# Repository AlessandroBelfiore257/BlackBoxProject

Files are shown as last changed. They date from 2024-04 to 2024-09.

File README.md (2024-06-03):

# Black-box per flotte a noleggio: monitoraggio/tracking veicoli, segnalazione allarmi e profilazione guida

## Che cosa viene realizzato?
Progetto Open Source che prevede la realizzazione di una scatola nera collocabile all'interno di veicoli appartenenti ad una compagnia di autonoleggio; la black box è in grado di svolgere le seguenti funzionalità:
1. Monitoraggio dati e tracking del veicolo
2. Segnalazione di allarmi. Questi possono essere dovuti ad un rilevamento di una situazione di incidente, ad un malfunzionamento del veicolo o ad un comportamento non corretto da parte del guidatore
3. Profilazione guida: sulla base di alcuni parametri posso raggruppare i guidatori (i clienti dell'autonoleggio) in certi cluster e classificarli come prudenti o negligenti

## In che ambito utilizzarlo? 
La black box è un prodotto collocabile all'interno di qualsiasi tipo di veicolo appartenente ad una compagnia di autonoleggio. Nasce con l'obiettivo di agevolare e
migliorare il servizio offerto alla clientela della compagnia (soccorso in caso di incidente, carro attrezzi, rilevamento immediato di un malfunzionamento del veicolo...). Inoltre, grazie alle sue molteplici funzionalità, è possibile monitorare la guida di qualsiasi veicolo appartenente alla flotta.

## Perchè acquistare tale prodotto per la compagnia di autonoleggio?
- Monitoraggio dati veicolo
- Geolocalizzazione (utile anche in caso di furto oltre che per le emergenze)
- Emergenze (guasto, malessere, incidente)
- Rilevamento azioni non lecite eseguite sul veicolo noleggiato
- Profilazione del guidatore ("Pay-as-you-drive")
- Maggiori benefici per il cliente: assistenza immediata per qualsiasi situazione "scomoda"

## Risorse utilizzate 
- OBD elm 327 bluetooth
- ESP32
- GPS GY-NEO 6M
- Accelerometro GY-521
- RTC DS3231 I2C
- Display LCD
- Sensore di Gas, Fumo e Qualità dell'Aria MQ-2
- Sensore di alcool MQ-3
- 3 Led
- 3 Resistori
- 1 Bottone
- 2 Breadboard da 830 pin
- Diversi jumper di lunghezza variabile
- Power bank

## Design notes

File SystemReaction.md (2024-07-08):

_A seguito di una particolare situazione riconosciuta dai sensori viene descritto il funzionamento/comportamento atteso della black box_

## Azione-reazione
### Le funzionalità sono 3:
#### Tracking:
Invio coordinate GPS (latitudine e longitudine e direzione) ad un server remoto, immagazzino i dati e dopo averne raccolti abbastanza provare a ricostruire il tragitto percorso.
#### Seganalazione allarmi:
- Assistenza incidente:
Simulare una dinamica di incidente e verificare che venga notificata la centrale operativa con tutte le informazioni utili (G-force, velocità, latitudine, longitudine e momento dell'impatto).
- Assistenza cliente:
Simulare entrambe le features (Invio notifica a server remoto per qualsiasi bisogno e invio notifica a server remoto per necessità di carroattrezzi), con "invio notifica" si intende che il server remoto riceva una notifica da un qualunque veicolo dell'autonoleggio con un opportuno messaggio che ne indica la descrizione del problema e con le informazioni utili ad esempio coordinate gps in caso di notifica per carroattrezzi.
- Avvertimento di alcuni sistemi non funzionanti / segnalazione di alcune situazioni anomalie: 

_*LED GIALLO:*_

1) Simulare la presenza di fumo nell'abitacolo, verificare l'accensione del led giallo e la notifica al conducente, se ne viene rilevata la presenza per un periodo prolungato e continuo (2/3 giorni) avvisare la centrale del comportamento scorretto del cliente.

2) Rilevamento guida su terreni non asfaltati con la modifica di alcuni dati ottenuti dall'accelerometro, verificare l'accensione del led giallo e la notifica al conducente, se viene rilevata un'attività frequente in fuori strada viene contattata la centrale.

3) Rilevamento guida in zona non autorizzata grazie alle coordinate GPS, verificare l'accensione del led giallo e la relativa notifica al conducente. Se la posizione del veicolo continua ad essere al di fuori del range voluto, viene inviata una notifica alla centrale operativa.

4) Rilevamento attività di rimorchio, se viene rilevata un'attività di trasporto viene azionato il led giallo e mandata una notifica al conducente, dopo un periodo prestabilito viene avvisata la centrale dell'attività non lecita.

_*LED ROSSO:*_  

1) A seguito di più rilevamenti di una frenata anomala, viene immediatamente segnalato alla centrale il guasto, inoltre il led rosso viene acceso. 

2) Il consumo anomalo di carburante viene rilevato a seguito del trasferimento dei dati ad un server remoto e a seguito di un'accurata analisi di essi, lo stato del led risulta essere rosso.

3) La qualità dell'aria e l'alcool possono essere simulate con la relativa presenza di scarsa Co2 o presenza di alcool, per verificarne il corretto funzionamento è necessario che il led assuma lo stato rosso e che venga segnalata la situazione con un opportuno messaggio al cliente e alla centrale.

4) Modificando i dati della rete can bus: temperatura del liquido di raffreddamento, temperatura dell'olio motore e la coppia del motore con opportuni valori critici, il sistema deve reagire inviando un opportuno segnale al conducente e alla centrale operativa e con l'azionamento del led rosso.

#### Profilazione guida
Si propone di eseguire ripetutamente lo stesso percorso in automobile, affrontandolo con tre distinti stili di guida: tranquillo, moderato e brusco, al fine di valutare e confrontare gli effetti di tali stili sulla dinamica di guida. Si osserverà un diverso score ottenuto dalla board nei tre casi distinti.

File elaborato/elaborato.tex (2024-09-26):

%%%%%%%%%%%%%%%%%%%%%%%%%%%%%%%%%%%%%%%%%%%%%%%%%%%%%%
\documentclass[12pt, a4paper, italian]{report}
\usepackage{template}  % Assicurati che questo pacchetto esista e non crei conflitti

\usepackage[colorinlistoftodos]{todonotes}
\usepackage{tikz}
\usepackage{tocloft}
\usepackage{adjustbox}
\usepackage{amsmath}
\usepackage[utf8]{inputenc}
\usepackage{listings}
\usepackage{xcolor}

\numberwithin{figure}{chapter}
\numberwithin{table}{chapter}

\usetikzlibrary{shapes.geometric, arrows, positioning, calc}

\lstset{
  language=C++,
  basicstyle=\ttfamily\small\color{black}, % Codice in nero
  keywordstyle=\bfseries,
  commentstyle=\itshape,
  stringstyle=\color{red},
  numberstyle=\tiny\color{gray},
  numbersep=5pt,
  frame=single, % Bordo attorno al codice
  rulecolor=\color{black}, % Colore del bordo
  backgroundcolor=\color{white}, % Sfondo bianco
  tabsize=2,
  breaklines=true,
  breakatwhitespace=false,
  showspaces=false,
  showtabs=false,
  numbers=left,
  showstringspaces=false
}

\tikzstyle{startstop} = [rectangle, rounded corners, minimum width=3cm, minimum height=1cm, text centered, draw=black, fill=red!30]
\tikzstyle{process} = [rectangle, minimum width=3cm, minimum height=1cm, text centered, draw=black, fill=orange!30]
\tikzstyle{decision} = [diamond, aspect=2, minimum width=3cm, minimum height=1cm, text centered, draw=black, fill=green!30]
\tikzstyle{arrow} = [thick,->,>=stealth]

%%%%%%%%%%%%%%%%%%%%%%%%%%%%%%%%%%%%%%%%%%%%%%%%%%%%%%
% packages...
% Package di formato
\usepackage[a4paper]{geometry}		% Formato del foglio
\usepackage[italian]{babel}			% Supporto per l'italiano
\usepackage{lscape}
%\usepackage[a-1b]{pdfx}			% File conforme allo standard PDF-A (obbligatorio per la consegna)

% Package per la grafica
\usepackage{graphicx}				% Funzioni avanzate per le immagini
\usepackage{hologo}					% Bibtex logo with \hologo{BibTeX}
\usepackage{enumitem}

% Citazioni e bibliografia
\usepackage[style=italian]{csquotes}
\usepackage[backend=biber,style=numeric,sorting=none]{biblatex}
\addbibresource{bibliografia.bib}
\usepackage[toc]{appendix}
\usepackage{epigraph}

% Package tipografici
\usepackage{lmodern,textcomp}		% Latin Modern font
\usepackage{amssymb,amsmath,amsthm} % Simboli matematici

% Sistema note a pié di pagina nelle tabelle e nelle figure
\usepackage{footnote}
\makesavenoteenv{tabular}
\makesavenoteenv{table}
\makesavenoteenv{figure}

% Package ipertesto
\usepackage{url}					% Visualizza e rende interattivi gli URL
\usepackage{hyperref}				% Rende interattivi i collegamenti interni

% Path immagini
\graphicspath{ {./images/} }

% Configurazione dei piè di pagina
\usepackage{fancyhdr}  % Per configurare intestazioni e piè di pagina
\pagestyle{fancy}
\fancyhf{}
\fancyfoot[C]{\thepage}  % Piè di pagina centrato con numero di pagina
%%%%%%%%%%%%%%%%%%%%%%%%%%%%%%%%%%%%%%%%%%%%%%%%%%%%%
\setlength {\marginparwidth }{2cm}
\begin{document}

% Frontespizio
\begin{titlepage}
\begin{center}
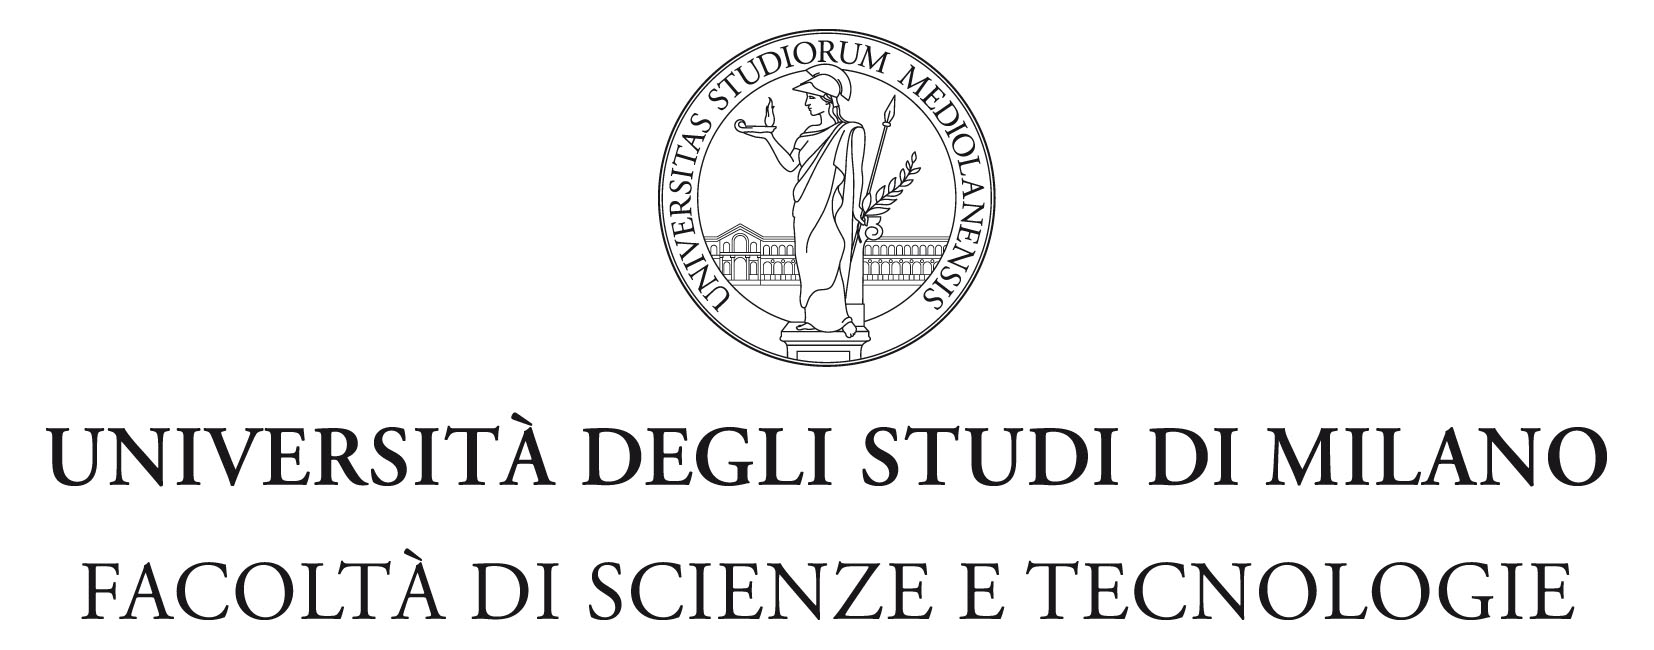
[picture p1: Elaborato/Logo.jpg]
\\
{\large{\bf Corso di Laurea in Informatica}}
\end{center}
\vspace{12mm}
\begin{center}
{\huge{\bf Black-box per flotte a noleggio: monitoraggio/tracking veicoli, segnalazione allarmi e profilazione guida}}\\
\end{center}
\vspace{12mm}
\begin{flushleft}
{\large{\bf Relatore: Prof. Andrea Trentini}}
{\large{}}\\
\vspace{4mm}
{\large{\bf Correlatore: Dott. Alexjan Carraturo}}
{\large{}}\\
\end{flushleft}
\vspace{12mm}
\begin{flushright}
{\large{\bf Tesi di Laurea di:}}
{\large{Alessandro Belfiore}}\\
{\large{\bf Matr. 975826}}\\
\end{flushright}
\vspace{4mm}
\begin{center}
{\large{\bf Anno Accademico 2023/2024}}
\end{center}
\end{titlepage}

\newpage
\thispagestyle{empty}
\null
\newpage

\tableofcontents

% o sections (dipende dal documentclass)
\chapter{Introduzione}
Il settore assicurativo è stato tra i primi ad intuire le potenzialità del tracciamento GPS per monitorare gli spostamenti di un automobilista ed assisterlo in caso di emergenza. Ad esempio, in caso di incidente, il GPS può segnalare la posizione esatta ai soccorsi o, in caso di furto, informare le forze dell'ordine in tempo reale. Queste funzionalità sono rese possibili dall'introduzione della cosiddetta “scatola nera” o black-box: un piccolo dispositivo installato sull'auto dell'assicurato, capace di registrare non solo tutti gli spostamenti dell'auto, ma anche il comportamento di guida del conducente. La black-box può essere utilizzata dalle compagnie assicurative per profilare i clienti, offrendo polizze personalizzate e adattate al tipo di utilizzo del veicolo.\cite{fracassi2012} % \todo{AT: fai uno spellcheck, accenti sbagliati}
%\todo{AT: accennare già al fatto della profilazione?}
\section{Cos'è una scatola nera?}
La black-box è un dispositivo elettronico utilizzato principalmente per monitorare e registrare vari parametri di funzionamento del veicolo e il comportamento del conducente. Nonostante il termine sia spesso associato alle registrazioni di volo degli aerei, nel contesto automobilistico e assicurativo, la scatola nera ha una funzione leggermente diversa ma altrettanto cruciale. Si presenta una descrizione dettagliata nei due paragrafi seguenti:

\begin{figure}[h] \centering
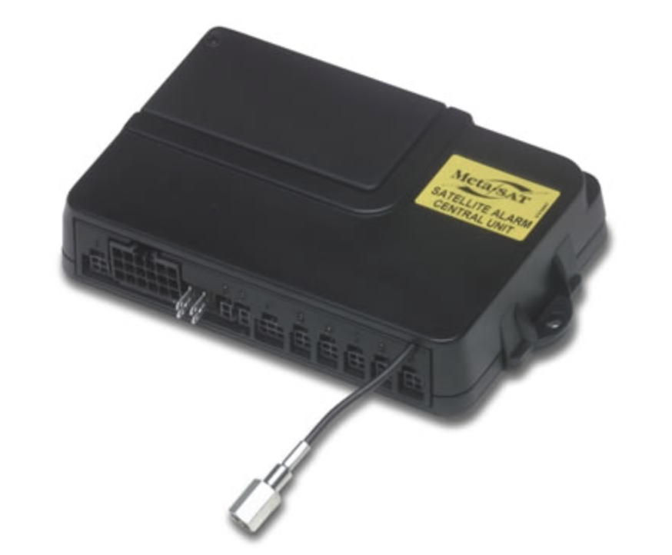
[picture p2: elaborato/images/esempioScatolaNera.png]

\caption{Esempio di scatola nera\protect\footnotemark (fonte: driving test tips)}
\label{fig:scatolaNera}
\end{figure}
\footnotetext{Presa da: \url{https://www.drivingtesttips.biz/wp-content/uploads/2016/01/car-insurance-black-box.jpg}}

\subsection{Utilità}
\begin{itemize}
    \item \textbf{Tracciamento GPS}: registra i movimenti del veicolo, inclusi i percorsi effettuati, le velocità raggiunte e le soste. Questo permette di localizzare il veicolo in caso di furto e di fornire assistenza immediata in caso di emergenza.\cite{khin2018real}
    \item \textbf{Monitoraggio del comportamento di guida}: registra il comportamento del conducente, come accelerazioni brusche, frenate improvvise, velocità eccessive e svolte pericolose. Questi dati permettono di valutare lo stile di guida e possono essere utilizzati per migliorare la sicurezza stradale.\cite{hermawan2020acquisition}
    \item \textbf{Supporto in caso di incidenti}: fornisce dati cruciali sugli incidenti, come la velocità al momento dell'impatto e la posizione esatta dell'incidente. Queste informazioni possono essere molto importanti per le indagini post-incidente e per la richiesta di soccorsi. \cite{thompson2010using}
\end{itemize}
\subsection{Importanza}
L'importanza di una black-box è data dai benefici che si possono trarre da essa: 
\begin{itemize}
    \item \textbf{Assistenza rapida}: in caso di incidente, la scatola nera può inviare automaticamente la posizione ai servizi di emergenza, riducendo i tempi di risposta.
    \item \textbf{Recupero dei veicoli rubati}: la localizzazione GPS permette di tracciare e recuperare rapidamente veicoli rubati, a meno che il dispositivo non venga rimosso o disattivato. % \todo{AT: se non lo rimuovono/staccano}
    \item \textbf{Polizze assicurative personalizzate}: le compagnie assicurative possono utilizzare i dati registrati per profilare i clienti e offrire polizze personalizzate basate sul comportamento alla guida e sull'uso del veicolo, incentivando una guida più responsabile attraverso sconti per chi mantiene uno stile di guida prudente.
    \item \textbf{Miglioramento della sicurezza}: i dati raccolti possono essere utilizzati per educare i conducenti a comportamenti di guida sicuri, contribuendo a ridurre il rischio di incidenti. Un'indagine dell'ANIA (Associazione Nazionale delle Imprese Assicurative) ha stabilito che chi installa una black-box ha una condotta di guida più responsabile \cite{diminuzioneIncidenti}, diminuendo quindi la probabilità di provocare sinistri. Lo studio, precedentemente citato, ha rilevato una riduzione della sinistrosità per i veicoli controllati dal congegno quasi doppia rispetto a quella delle auto che non montano il sistema di sorveglianza. % \todo{AT: prima o poi mi aspetto considerazioni sull'aspetto privacy} -> Aggiunte al capitolo 2.4
\end{itemize}
\section{Obiettivi del progetto}
Il principale obiettivo di questo progetto è quello di sviluppare una black-box avanzata per veicoli appartenenti ad una flotta di autonoleggio a lungo termine, che si distingua dalle soluzioni tradizionali per la sua capacità di diagnosticare sia il veicolo che il comportamento del conducente. Le tradizionali black-box non solo registrano i dati di viaggio, ma svolgono anche funzioni fondamentali come il monitoraggio costante del veicolo, il tracciamento degli incidenti e la richiesta automatica di assistenza in caso di emergenza. La black-box di cui tratta questo elaborato, oltre a queste funzionalità di base, introduce due caratteristiche innovative che ne ampliano ulteriormente le potenzialità.

\vspace{1cm}

La \textbf{prima caratteristica distintiva} è la capacità di rilevare e segnalare tempestivamente sia allarmi critici che di minore gravità, relativi a problemi meccanici del veicolo e comportamenti inappropriati del conducente. Questo sistema avanzato di diagnostica è in grado di identificare malfunzionamenti interni dell'autovettura, come anomalie nel motore, nonché situazioni di pericolo come la presenza di gas nell'abitacolo. Inoltre, è capace di monitorare e segnalare comportamenti non leciti del conducente: la presenza di fumo nell'abitacolo (che potrebbe essere un vincolo da rispettare imposto dalla compagnia), la guida sotto l'effetto di alcolici, l'utilizzo del veicolo su strade non asfaltate, la guida fuori dal territorio nazionale o il trasporto di un rimorchio senza autorizzazione.

\vspace{1cm}

La \textbf{seconda caratteristica innovativa} è la generazione automatica di un punteggio di guida per il conducente. Tale punteggio viene calcolato sulla base dei dati raccolti durante la guida, valutando il comportamento al volante del conducente. Il punteggio serve non solo come feedback per il conducente, aiutandolo a migliorare le proprie abitudini di guida, ma potrebbe essere anche utilizzato dalle compagnie assicurative per offrire polizze personalizzate e vantaggiose, stimolando il conducente a mantenere uno stile di guida più prudente. È importante sottolineare che questa profilazione del conducente non richiede l'intervento di un esperto lato server remoto, poiché è la stessa black-box ad elaborare e generare automaticamente il punteggio di guida.

\vspace{1cm}

Il progetto mira a creare una black-box che non solo registra e monitora i dati di viaggio e le condizioni del veicolo, ma offre anche un sistema di diagnostica integrato in grado di riconoscere malfunzionamenti interni del veicolo, comportamenti inappropriati del conducente e la capacità di valutare quest'ultimo sulla base del suo stile di guida; migliorando sicurezza ed efficienza del veicolo e contribuendo ad una guida più responsabile e consapevole.

\chapter{Stato dell'arte}
La \textbf{scatola nera}, chiamata anche black-box o EDR (Event Data Recorder, ovvero registratore di dati di evento), è un dispositivo che registra dati come la posizione (determinata tramite GPS), la velocità, le accelerazioni, le decelerazioni, le frenate e la frequenza di attivazione dei sistemi di sicurezza, trasmettendoli poi a una centrale operativa.
Quelle che sono comunemente indicate come ``scatole nere" sono localizzatori satellitari GPS installati a bordo dell'auto, ideate dalle assicurazioni come strumento con lo scopo di ridurre le \textbf{frodi assicurative}.
\section{Gestioni attuali di tracking per veicoli}
Il principale vantaggio del tracking dei veicoli è quello di facilitare il rintracciamento del veicolo in caso di furto, grazie al localizzatore GPS. Naturalmente, il localizzatore ha un ruolo rilevante anche nella gestione degli incidenti, come verrà discusso nel prossimo paragrafo.
% \todo{AT: italiano da rivedere!}
\section{Gestioni attuali delle emergenze e dei sistemi di allarmi in uso}
\subsection{Vantaggi e Svantaggi nella gestione delle emergenze}
\subsubsection{Vantaggi}
Grazie all'installazione di una black-box sul proprio veicolo, al monitoraggio continuo e al tracking di esso, è possibile, in caso di incidente, visualizzare il luogo dell'accaduto immediatamente e ricostruire con precisione la dinamica degli incidenti stradali. Tramite questo strumento le compagnie assicurative sono in grado di ricostruire più facilmente la dinamica di un sinistro stradale. Questo non solo avvantaggia la compagnia, ma anche il guidatore, che vedrà diminuire il tempo
%\todo{AT: o anche però non vedersi rimborsare perché gli affibbiano la colpa, senza possibilità di contestazione} -> inserita questa considerazione nella sezione svantaggi
per ottenere il risarcimento del danno, dato che grazie alla black-box è possibile evitare le lunghe procedure per l'accertamento delle responsabilità in un incidente.
\subsubsection{Svantaggi}
Le black-box attuali sono in grado di registrare la velocità del veicolo e questo fa si che in un ipotetico incidente senza alcun tipo di colpa, se fosse stata registrata una velocità anche poco sopra al limite, si potrebbe riconoscere al guidatore una piccola parte di responsabilità nel sinistro. Questo aspetto sottolinea un potenziale rischio per il guidatore: \textbf{sebbene la black-box possa accelerare il processo di risarcimento, potrebbe anche attribuire la colpa o una responsabilità parziale in modo inequivocabile, rendendo difficile contestare tale decisione}. Questo non solo potrebbe portare ad una riduzione del risarcimento, ma anche causare conseguenze legali o assicurative impreviste per il guidatore.

\vspace{1cm}

Nei vari contratti di noleggio \cite{hertz_pdf} vengono proposti dei termini e delle condizioni sull'utilizzo dell'autovettura, quali ad esempio non utilizzare il veicolo nelle seguenti condizioni: 
\begin{itemize}
    \item  sotto l'effetto di alcool.
    \item da persone sprovviste di patente o con validità scaduta.
    \item fuori strada o su strade inadatte.
    \item per recarsi all'estero salva preventiva autorizzazione concessa dal noleggiante.
    \item per trainare o spingere qualsiasi altro veicolo, rimorchio o oggetto senza consenso del noleggiatore.
\end{itemize}
Tutti questi divieti vengono citati all'interno del contratto assicurativo, non è possibile però stabilire se uno tra questi non dovesse essere rispettato.

\section{Soluzioni esistenti per la profilazione guidatori}
Alcune grandi compagnie di assicurazioni, quali ad esempio \textbf{Generali}, propongono il servizio \textbf{stile di guida} che permette di ottenere ulteriori sconti sulla polizza negli anni a seguire \cite{Generali}. Si tiene a precisare la parola ``ulteriori" dato che già l'installazione di una black-box prevede uno sconto compreso tra il 15/20\%, sul totale dell'assicurazione.% \todo{AT: il costo effettivo è in realtà nascosto, perché l'assicurazione ha più leva per non pagarti, inoltre paghi con la rinuncia alla tua privacy}

\section{Privacy e tutela dei dati}
Il Regolamento europeo vieta espressamente che la scatola nera registri conversazioni o usi i dati sensibili del guidatore, consentendo così l'anonimato del conducente e l'accesso ai dati solo in caso di collisione \cite{RegolamentoEU}.
La scatola nera ha sollevato molti \textbf{dubbi sulla questione privacy} dei clienti. Infatti, i dati vengono raccolti in un database e possono essere elaborati e analizzati soltanto dagli addetti ai lavori. Questa procedura insospettisce i clienti sul possibile \textbf{uso improprio} dei dati che, per esempio, potrebbero essere utilizzati a fini commerciali dalle compagnie assicurative per proporre prodotti ad hoc a prezzi non troppo vantaggiosi. Tuttavia, l’\textbf{ANIA} (Associazione Nazionale fra le Imprese Assicuratrici) assicura che \textbf{le compagnie sono a conoscenza soltanto dei dati che il cliente autorizza a far conoscere} firmando il modulo per la tutela approvato dal GDPR \cite{Generali}.

\section{Quanto è comune la scatola nera in Italia?}
L'uso della scatola nera in Italia inizia ad essere rilevante. Il trend di crescita non si è mai interrotto negli ultimi 10 anni e la percentuale di auto dotate di black-box è passata dal 6\% del 2013 al 23,2\% del 2020 (primo semestre)  \cite{Telepass}. I dati del 2021 del report IVASS confermano una diffusione più alta nei centri urbani del Sud Italia, come Caserta (65,5\%), Napoli (52,5\%) e Reggio Calabria (38,6\%). Le percentuali calano sotto il 10\% nelle città e nelle province del Nord come Udine (9\%), Trento (8\%), Belluno (7,3\%) e Bolzano (4,4\%). Tuttavia, è importante non considerare tali dati come indicatori della prudenza degli automobilisti nelle aree citate, in quanto, la maggior diffusione della black-box nelle regioni del sud Italia, dove i premi assicurativi sono più elevati e in alcune regioni possono arrivare a diverse migliaia di euro all'anno, è principalmente correlata alla possibilità di ottenere sconti significativi sulla polizza, compensando così tali costi elevati.

\chapter{Funzionalità del sistema}
\section{Monitoraggio}
Il monitoraggio consiste nella raccolta dati di alcuni parametri provenienti dal lettore OBD \ref{sec:capitolo432} % \todo{AT: la prima volta che usi un termine non di uso comune devi spiegarlo o mettere un rimando (anche in avanti) alla spiegazione} 
e da alcuni sensori installati sulla black-box. 
Il motivo per cui si è scelto di monitorare lo stato del veicolo è quello di ottenere una visione completa della sua salute. In particolare, i dati che vengono registrati sono: l'\textbf{accelerazione}, misurata grazie ad un accelerometro, utile per analizzare il comportamento dinamico del veicolo; la \textbf{presenza di vapori alcolici} nell'abitacolo, rilevata da un sensore per garantire la sicurezza del conducente e dei passeggeri; per assicurare una \textbf{qualità dell'aria} adeguata all'interno del veicolo, viene utilizzato un sensore specifico che rileva vari inquinanti. Il modulo GPS fornisce \textbf{coordinate} precise, fondamentali sia per la tracciabilità del veicolo in caso di furto sia per analizzare i percorsi abituali. Attraverso un lettore OBD, inoltre, viene monitorata  costantemente la \textbf{temperatura del liquido di raffreddamento} e dell'\textbf{olio motore}. Vengono poi registrati la \textbf{coppia del motore} per valutare le sue prestazioni e il \textbf{voltaggio della batteria} per prevenire problemi elettrici.
Infine, il dato relativo al \textbf{livello del carburante} permette di tenere traccia dell'autonomia del veicolo. 
\section{Tracking}
Questa funzionalità del sistema viene adoperata per localizzare i veicoli della flotta \cite{al2012hybrid}. Il sistema di tracking è in grado di generare la posizione esatta del veicolo usando due parametri: la latitudine e la longitudine. I dati di geolocalizzazione, per ogni slot temporale di 2 minuti, vengono trasferiti al server remoto della centrale operativa dell'autonoleggio. A posteriori potrebbero essere utilizzati per visualizzare i percorsi abituali del cliente o il percorso effettuato un preciso giorno. Il sistema di tracking è utile soprattutto in caso di furto del veicolo.
Infatti, il ricevitore GPS riceve informazioni dal satellite nel formato NMEA (National Marine Electronics Association), quest'ultime vengono processate dall'esp32 e trasmesse al server remoto via GSM. Il server, una volta ricevuto i dati, li memorizza in locale per analisi future. 

\begin{figure}[h] \centering
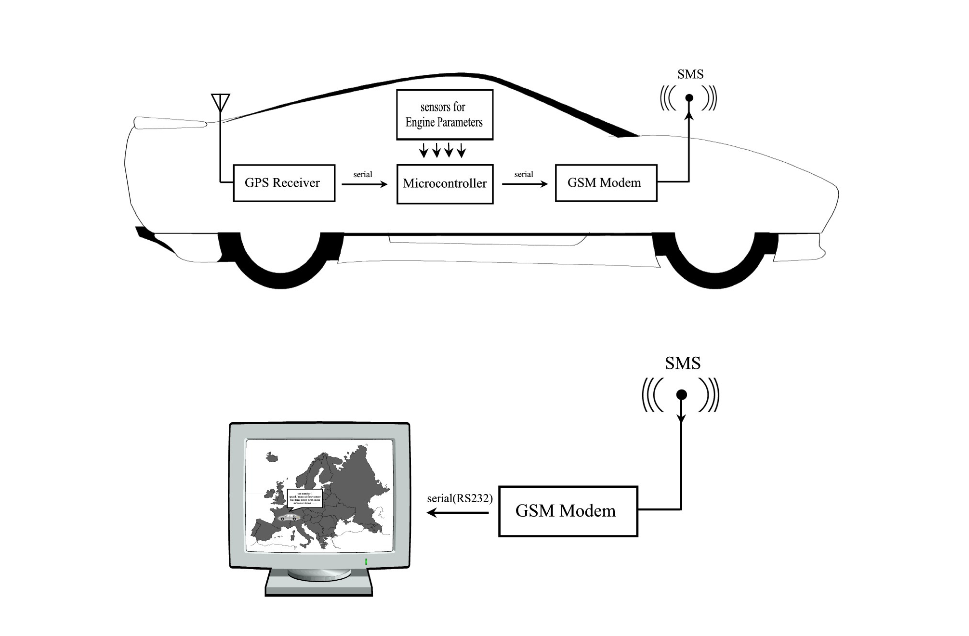
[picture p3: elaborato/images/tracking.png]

\caption{L'architettura del sistema: localizzazione GPS e modulo GSM\protect\footnotemark (fonte: ResearchGate)}
\label{fig:trackingGPS}
\end{figure}
\footnotetext{Presa da: \url{https://www.researchgate.net/profile/Mohammad-Alkhedher/publication/51989090/figure/fig5/AS:668830275760151@1536472972974/The-system-architecture-GPS-tracking-and-GS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}}

In molti casi il GPS potrebbe fornire una risposta errata o non sufficientemente precisa, dovuta a molti fattori esterni quali: condizioni del tempo atmosferico e/o dell'ambiente che circonda il veicolo.

\section{Segnalazione di allarmi}
Il meccanismo di segnalazione allarmi prevede 3 diversi tipi di dinamiche che verranno presentate in dettaglio nei seguenti paragrafi. 
\subsection{Incidente}
L'assistenza incidente tratta la dinamica relativa ad un incidente stradale, inviando le coordinate GPS ed un insieme di informazioni utili ad una stazione remota dell'autonoleggio. Sarà compito della stazione avvisare i soccorsi che si recheranno nel preciso punto di impatto. 
\begin{figure}[h] \centering
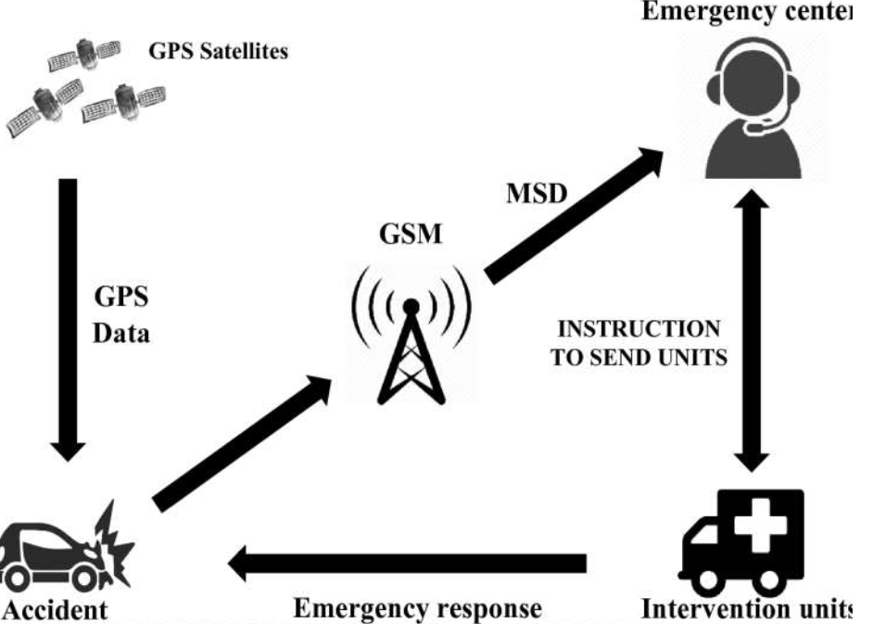
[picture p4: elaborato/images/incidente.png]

\caption{Situazione di emergenza dovuta ad un incidente\protect\footnotemark (fonte: ResearchGate)}
\label{fig:emergenzaIncidente}
\end{figure}
\footnotetext{Presa da: \url{https://www.researchgate.net/publication/51989090_Hybrid_GPS-GSM_localization_of_automobile_tracking_system}}

Sostanzialmente, il meccanismo si divide in due fasi: \textbf{rilevamento} e \textbf{notifica}, vedi figura \ref{fig:rilevamentoInvioIncidente}.
% \todo{AT: i diarammi di flusso sanno di ``antico'', li ridurrei in dimensione o eliminerei} -> ne ho ridotto le dimensioni 
\begin{figure}[h]
    \centering
    \resizebox{0.5\textwidth}{!}{
        \begin{tikzpicture}[node distance=2cm]

        % Nodi del diagramma
        \node (start) [startstop] {Start};
        \node (readsensor) [process, below of=start] {Read the status of sensor};
        \node (readgps) [process, below of=readsensor] {Read the data from GPS};
        \node (decision) [decision, below of=readgps, yshift=-1cm] {Sensor is triggered?};
        \node (sendSMS) [process, right of=decision, xshift=4cm] {Send SMS using GSM};
        \node (end) [startstop, below of=sendSMS] {End};

        % Frecce del diagramma
        \draw [arrow] (start) -- (readsensor);
        \draw [arrow] (readsensor) -- (readgps);
        \draw [arrow] (readgps) -- (decision);

        % Etichette ``Yes" e ``No"
        \node at ($(decision.west)!-0.2!(readsensor.east)$) [yshift=3cm] {No};
        \node at ($(decision.east)!0.5!(sendSMS.west)$) [yshift=0.3cm] {Yes};

        \draw [arrow] (decision) -| ++(-3,0) |- (readsensor);
        \draw [arrow] (decision) -- (sendSMS);
        \draw [arrow] (sendSMS) -- (end);

        \end{tikzpicture}
    }
    \caption{Diagramma di flusso per il monitoraggio dell'accelerometro ed eventuale invio SMS}
    \label{fig:rilevamentoInvioIncidente}
\end{figure}

I sensori maggiormente coinvolti sono l'accelerometro, il GPS e il dato relativo alla velocità del veicolo, proveniente dalla rete can bus. Nella fase di campionamento, l'accelerometro continua ad estrarre informazioni relative alla forza G sperimentata dagli occupanti. Il GPS, nella fase di notifica, è utile per inviare le coordinate alla stazione remota. Infine, la velocità del veicolo, coinvolta sempre in fase di notifica, viene mandata alla stazione remota e può essere utilizzata per future ricostruzioni/analisi dell'incidente. \cite{shubham2021survey}

Per il rilevamento di una situazione di incidente, si può utilizzare un accelerometro. In un evento di questo tipo la black-box subirà la stessa accelerazione degli occupanti del veicolo. La forza G che si ricava dall'accelerazione deve essere ragionevolmente alta per un incidente, per questo non vengono considerati incidenti se tutte le accelerazioni sono inferiori a 4G \cite{thompson2010using}. A tale proposito, sulle auto gli airbag non vengono altro che azionati dal superamento di una certa soglia di accelerazione. Come secondo filtro, viene utilizzato un sistema di conferma per evitare i falsi positivi: all'utente vengono concessi 30 secondi per annullare il rilevamento della situazione di incidente, terminato questo breve periodo, il messaggio verrà trasmesso al server remoto in automatico, in caso di annullamento si ritornerà ad una situazione di partenza, vedi figura \ref{fig:diagramma-flusso-incidenti}.

\begin{figure}[h]
    \centering
    \resizebox{0.5\textwidth}{!}{
    \begin{tikzpicture}[node distance=2cm, every node/.style={font=\small}]

    % Nodi del diagramma
    \node (start) [startstop] {Start};
    \node (readdata) [process, below of=start] {Read data};
    \node (gforcetriggered) [decision, below of=readdata] {G force triggered?};
    \node (incidentdetection) [process, below of=gforcetriggered, yshift=-0.5cm] {Rilevamento incidente};
    \node (userabort) [decision, below of=incidentdetection, yshift=-0.5cm] {User abort?};
    \node (sendSMS) [process, right of=userabort, xshift=3cm] {Send accident SMS};
    \node (end) [startstop, below of=sendSMS] {End};

    % Etichette ``Yes" e ``No"
    \node at ($(gforcetriggered.east)!0.5!(readdata.east)$) [xshift=1.3cm] {No};
    \node at ($(gforcetriggered.south)!0.5!(incidentdetection.north)$) [xshift=0.5cm] {Yes};
    \node at ($(userabort.east)!0.5!(sendSMS.west)$) [yshift=0.3cm] {No};
    \node at ($(readdata.south)!0.5!(userabort.north)$) [xshift=-3.2cm] {Yes};

    % Frecce del diagramma
    \draw [arrow] (start) -- (readdata);
    \draw [arrow] (readdata) -- (gforcetriggered);
    \draw [arrow] (gforcetriggered) -- (incidentdetection);
    \draw [arrow] (incidentdetection) -- (userabort);
    \draw [arrow] (userabort.west) -| ++(-1,0) |- (readdata.west);
    \draw [arrow] (gforcetriggered.east) -| ++(0.5,0) |- (readdata.east);
    \draw [arrow] (userabort) -- (sendSMS);
    \draw [arrow] (sendSMS) -- (end);

    \end{tikzpicture}
    }
    \caption{Diagramma di flusso per il rilevamento di incidenti e invio SMS}
    \label{fig:diagramma-flusso-incidenti}
\end{figure}

\begin{flushleft}
    \begin{minipage}[t]{0.3\textwidth}
        \scriptsize
        \begin{align*}
            \text{Incidente} &= I \\
            \text{Accident\_threshold} &= 1 \\
        \end{align*}
    \end{minipage}
    \vspace{0.5cm} % Aggiunge uno spazio verticale tra la legenda e la formula
    \begin{minipage}[t]{0.7\textwidth}
        \begin{align*}
            I &= 
            \begin{cases}
                1 & \text{se } \left( \frac{\text{Accelerazione}}{4G} \right) \geq \text{Accident\_threshold} \text{ \&\& } \neg\text{userAbort} \\
                0 & \text{altrimenti}
            \end{cases}
        \end{align*}
    \end{minipage}
\end{flushleft}

A seguito dell'incidente, le informazioni che possono essere trasmesse sono: la \textbf{forza G}, per capire quanto effettivamente è stato forte l'impatto, la \textbf{velocità del veicolo}, per capire a quanto quest'ultimo stava andando, le \textbf{coordinate GPS}, per individuare il luogo in cui è avvenuto l'incidente e in che \textbf{momento} questo è avvenuto.

\subsection{Assistenza}
Il sistema include un pulsante che permette al conducente di comunicare direttamente con il server remoto (la centrale dell'autonoleggio), inviando un messaggio tramite GSM in caso di necessità.
\subsection{Rilevamento allarmi}
Il rilevamento di allarmi consiste nell'avvertire il conducente e la centrale dell'autonoleggio di alcuni sistemi del veicolo non funzionanti e/o di alcuni comportamenti non corretti da parte del conducente. Per gestire tale situazione, la black-box viene dotata di 3 led per indicare diversi tipi di situazioni e per suggerire al cliente il corretto comportamento da intraprendere nel caso dell'accensione di una spia (led) indicante una situazione di avvertimento o pericolo. 
\begin{itemize}
    \item Il led \textbf{verde} indica che il veicolo \textbf{funziona correttamente} e il \textbf{comportamento} del conducente è \textbf{corretto}.
    \item Il led \textbf{giallo} indica un \textbf{avvertimento}. Se vengono rilevati problemi di poca rilevanza o eseguite azioni non lecite, viene azionato il led. Dopo aver superato una certa soglia di tolleranza, indicante il numero di volte in cui è stato rilevato il problema o eseguita l'azione non lecita, viene avvertita la centrale operativa. Il motto di questa spia è: se un problema di poca rilevanza o un'azione non lecita persistono, avverto la centrale.
    \item Il led \textbf{rosso} indica una situazione di \textbf{pericolo}. In questo caso la centrale operativa viene avvertita immediatamente.
\end{itemize}

Di seguito verranno proposte le dinamiche delle situazioni per le quali viene attivata una spia gialla piuttosto che una rossa.

\subsubsection{Non critici (led giallo)}

\begin{itemize}
    \item Divieto di fumo all'interno dell'abitacolo per il mantenimento di un ambiente pulito e privo di odori sgradevoli per i successivi clienti.
    \item Rilevamento guida su terreni non adatti: fuoristrada o percorsi non asfaltati sono vietati al conducente per evitare danni al veicolo. 
    \item Rilevamento guida su aree geografiche non percorribili: non è possibile recarsi ovunque con il veicolo della compagnia, ad esempio fuori da una certa nazione, o da un insieme di queste.
    \item Rilevamento attività di trasporto/rimorchio: non è possibile trainare qualsiasi tipo di rimorchio con il veicolo a noleggio.
\end{itemize}

\subsubsection{Critici (led rosso)}

\begin{itemize}
    \item Temperatura anomala olio motore: il motore non lavora nel suo range di temperatura e potrebbe guastarsi.
    \item Temperatura liquido refrigerante: una temperatura troppo alta potrebbe danneggiare componenti del motore, causando gravi guasti.
    \item Coppia motore anomala: mantenere la coppia motore entro limiti ottimali è essenziale per garantire prestazioni efficienti e sicure del veicolo, prevenendo l'usura prematura del motore e della trasmissione. Se la coppia è troppo bassa, si rischia una scarsa accelerazione, d'altra parte se troppo alta, si può verificare un eccessivo consumo di carburante e possibili danni meccanici.
    \item Monitoraggio della qualità dell'aria nell'abitacolo: utile per prevenire qualunque perdita di gas proveniente dai vari impianti dell'automobile, prevenendo così incendi.
    \item Rilevamento presenza di alcool: non è consentito al conducente mettersi alla guida in stato di ebrezza. Questa attività può essere monitorata attraverso un sensore che rileva la presenza di etanolo nell'ambiente. \cite{ahmar2021road}
    \item Distanza di frenata anomala: analizzando dati di accelerazione, velocità e spazio percorso è possibile rilevare situazioni in cui la distanza di frenata è significativamente più lunga, ciò può indicare un problema al sistema frenante o all'aderenza dei pneumatici.
    \item Consumo anomalo di carburante: monitorando il consumo di carburante del veicolo e confrontandolo con i modelli di consumo attesi è possibile rilevare anomalie che potrebbero indicare problemi al motore.
\end{itemize}

\section{Profilazione del comportamento del guidatore}
\label{sec:AnalisiProfilazione}
Nel quadro del progetto dell'analisi della profilazione guida, vengono sfruttate tecnologie di acquisizione dati per ottenere una comprensione dettagliata del comportamento del guidatore. A tale scopo, viene fatto uso di due principali fonti di informazioni: i \textbf{dati provenienti dal sistema diagnostico di bordo OBD-II} e quelli registrati da un \textbf{accelerometro}. Questi dispositivi forniscono una vasta gamma di dati in tempo reale, ad esempio, velocità, accelerazione, decelerazione (frenata) e angoli di sterzata, consentendo di valutare numerosi aspetti relativi alla guida. Attraverso l'analisi approfondita di tali dati, siamo in grado di creare profili individuali dei guidatori e di identificare modelli comportamentali distintivi che influenzano la sicurezza, l'efficienza e l'affidabilità del veicolo. Nel corso di questo paragrafo, si mostrerà come l'integrazione di queste tecnologie permetta di ottenere informazioni preziose per migliorare l'esperienza di guida e ottimizzare le operazioni di gestione della flotta.

\vspace{0.5cm} 

I principali parametri che vengono catturati per l'analisi del guidatore sono: \textbf{rpm} ovvero i giri motore al minuto, la \textbf{velocità} dell'auto, il \textbf{carico del motore} e la \textbf{posizione della valvola farfalla}, provenienti dalla rete CAN-BUS presente all'interno del veicolo, \textbf{accelerazione}, \textbf{decelerazione} e \textbf{sterzate} provengono invece dall'accelerometro. Una volta che la black-box riceve i valori dei parametri, essa è in grado di analizzarli e riconoscere situazioni riconducibili ad una guida impropria. Ogni 24h tali dati vengono adoperati per calcolare un punteggio di guida compreso tra 0 e 1. Questo punteggio potrebbe essere utilizzato dalla compagnia per varie finalità, come ad esempio fornire incentivi ai guidatori che adottano comportamenti di guida più sicuri. Ecco le principali fasi del sistema proposto \ref{diagrammaFlussoProfilazione}:

\begin{figure}[h!]
\centering
\resizebox{0.8\textwidth}{!}{ % Modifica il valore a seconda di quanto vuoi ridurre l'immagine
\begin{tikzpicture}
% Definizione dei nodi con posizionamento manuale
\node (data_sensing) [process] {Data sensing};
\node (data_acquisition) [process, right=1cm of data_sensing] {Data acquisition};
\node (data_processing) [process, right=1cm of data_acquisition] {Data processing};
\node (data_storage) [process, right=1cm of data_processing] {Storage vote};

% Connessione tra i nodi
\draw [arrow] (data_sensing) -- (data_acquisition);
\draw [arrow] (data_acquisition) -- (data_processing);
\draw [arrow] (data_processing) -- (data_storage);

\end{tikzpicture}
}
\caption{Diagramma di flusso dei dati}
\label{diagrammaFlussoProfilazione}
\end{figure}

ECU (master) è l'unità centrale di controllo del veicolo dove sono collegati tutti i vari attuatori e sensori del veicolo: motore, aria condizionata, livello carburante... Lo scanner OBD-II trasmette i dati dalla ECU alla board via Bluetooth. La board processa i dati ed è in grado di generare uno score del guidatore. Il punteggio [0,1] viene calcolato considerando:

\begin{itemize}
    \item Le accelerazioni e decelerazioni brusche. \cite{fazeen2012safe}
    \item Le strerzate sia a sinistra che a destra brusche. \cite{fazeen2012safe}
    \item Il rapporto (relativo) di velocità del veicolo con i giri del motore che deve essere compreso tra i valori di [0.9,1.3] per una buona guida. \cite{chen2015driving}
    \item Il rapporto (relativo) tra la valvola a farfalla e i giri del motore che deve essere compreso tra i valori di [0.9,1.3] per una buona guida. \cite{chen2015driving}
    \item Il carico del motore che deve essere compreso tra il 20\% e il 50\% per una buona guida. \cite{chen2015driving}
    \item Gli eccessi di velocità data dalla differenza tra i limiti imposti dalla legge e quelli reali del veicolo.
\end{itemize}

Per quanto riguarda il primo e il secondo punto è possibile utilizzare un accelerometro a 3 assi, utile per rilevare  le accelerazioni/decelerazioni e le sterzate improvvise: 

\begin{table}[h!]
  \centering
  \begin{tabular}{|c|c|c|}
    \hline
    \textbf{Asse} & \textbf{Direzione} & \textbf{Azione/Evento} \\
    \hline
    y & anteriore/posteriore & accelerazione/decelerazione (frenata) \\
    \hline
    x & sinistra/destra & sterzata \\
    \hline
    z & su/giù & strada dissestata \\
    \hline
  \end{tabular}
  \caption{Descrizione degli assi dell'accelerometro utilizzati nell'ambito della profilazione del conducente \cite{mpu6050_datasheet}}
  \label{tab:tabellaAccelerometro}
\end{table}

\begin{figure}[h]
  \centering
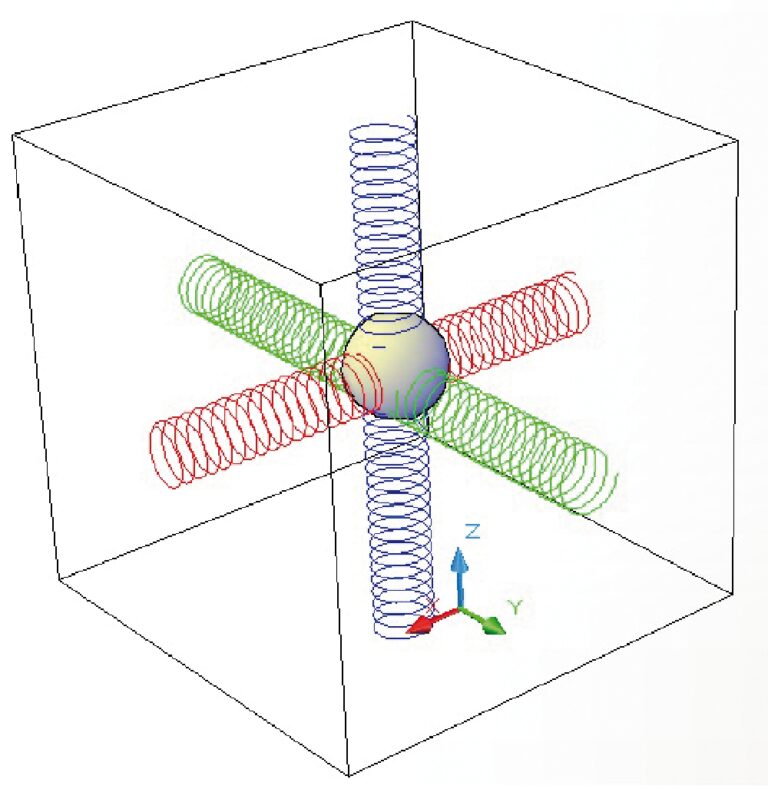
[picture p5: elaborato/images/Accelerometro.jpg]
  
  \caption{Modello meccanico di un accelerometro a 3 assi \protect\footnotemark (fonte: futura group progetti)}
  \label{fig:accelerometro}
\end{figure} %\todo{AT: non c'è fonte nella caption}
\footnotetext{Presa da: \url{https://futuranet.it/wp-content/uploads/2023/01/Figura-4-6-768x789.jpg}}

Il terzo e quarto punto sono, invece, calcolabili per via analitica raccogliendo dati provenienti dall'OBD-II. Per quanto riguarda l'ultimo punto (carico del motore espresso in \%) non si ha bisogno di alcuna manipolazione dei dati in quanto essi provengono direttamente dalla rete CAN-BUS.

\vspace{1cm}
% \todo{AT: il codice inserito qui senza un po' di spiegazione non va molto bene, va almeno fatta introduzione al perché lo mostri}
Nella figura seguente è riportato un esempio di implementazione di una parte dell'algoritmo di profilazione conducente, utilizzato per catturare gli eventi più critici che conducono ad una valutazione di guida spericolata. Questo frammento di codice illustra come vengono registrate le situazioni riconducibili ad una guida poco prudente; inoltre verso la fine del task, precisamente a riga 32, viene fatta una valutazione riguardante il numero di campionamenti fatti sino a quel momento: se il numero di campionamenti risulta essere soddisfacente, allora si può procedere alla valutazione del conducente:

\vspace{0.5cm}

\begin{lstlisting}
// Implementazione task relativo alla profilazione guida
void profilazioneCallback() {
  campionamento_Profilazione++;
  sensors_event_t a, g, temp;
  mpu.getEvent(&a, &g, &temp);

  float x = a.acceleration.x;
  float y = a.acceleration.y;

  // Sterzate sinistra e destra brusche
  if ((x / FORZA_G) > (STERZATA_DX_BRUSCA) || (x / FORZA_G) < (STERZATA_SX_BRUSCA)) {
    nRilevamentiSterzateBrusche++;
  }
  // Accelerazioni / decelerazioni brusche
  if ((y / FORZA_G) > (ACCELERAZIONE_BRUSCA) || (y / FORZA_G) < (DECELERAZIONE_BRUSCA)) {
    nRilevamentiAccDecBrusche++;
  }
  // Rapporto v su giri motore
  float fatt1 = ((kph / MAX_SPEED_CAR) / (rpm / MAX_RPM_CAR));
  if ((fatt1 < RANGE_INF) || (fatt1 > RANGE_SUP)) {
    nRilevamentiFatt1++;
  }
  // Rapporto posizione della valvola a farfalla su giri motore
  float fatt2 = ((throttle / 100) / (rpm / MAX_RPM_CAR));
  if ((fatt2 < RANGE_INF) || (fatt2 > RANGE_SUP)) {
    nRilevamentiFatt2++;
  }
  // Carico motore
  if ((load < LOAD_MIN) || (load > LOAD_MAX)) {
    nRilevamentiCaricoMotoreOutOfRange++;
  }
  if (campionamento_Profilazione == MAX_CAMPIONAMENTI_PROFILAZIONE) {  
    updateCampionamentoProfilazione();
  }
}
\end{lstlisting}

\vspace{1cm}

Per valutare il comportamento del guidatore, di seguito, vengono mostrati i vari livelli di punteggio del guidatore:

\begin{table}[h!]
  \centering
  \begin{tabular}{|c|c|}
    \hline
    \textbf{Driver score} & \textbf{Driving behaviour} \\
    \hline
    \(< 0.10\) & safe \\
    \hline
    0.10 - 0.18 & modest \\
    \hline
    0.19 - 0.38 & moderate risk \\
    \hline
    0.39 - 0.56 & risk \\
    \hline
     0.57 - 0.75 & reckless \\
    \hline
     \(> 0.75\) & critical \\
    \hline
  \end{tabular}
  \caption{Tabella di valutazione del conducente}
  \label{tab:tabellaValutativa}
\end{table}

Il punteggio del guidatore è inteso come la probabilità del rischio di procurare un incidente a seguito del viaggio osservato, pertanto sarà compreso tra 0 e 1.

\chapter{Implementazione del sistema}
\section{Architettura}

\subsection{Componenti hardware utilizzati}

Il microcontrollore principale utilizzato per l'elaborazione dei dati e la comunicazione con le periferiche è un \textbf{ESP-WROOM-32}, un chip di basso costo e bassa potenza con integrati i moduli WiFi e Bluetooth. 
Viene utilizzato un \textbf{Display LCD 16x2} utile per interagire con l'utente e avvisarlo in caso sia presente qualche problema al veicolo o viene rilevato qualche comportamento anomalo. \textbf{MQ-2} e \textbf{MQ-3} vengono adoperati come sensori per il rilevamento di gas e alcool, un \textbf{bottone} viene adoperato per la richiesta di assistenza alla centrale operativa, dei \textbf{led}, presenti in 3 colorazioni: rosso, giallo e verde, vengono adoperati come spie per richiamare, con un effetto visivo, all'attenzione dei possibili scenari che si potrebbero verificare. 
Un modulo \textbf{GPS GY-NEO-6M NEO6MV2} utile per le funzionalità di tracking e monitoraggio, un \textbf{accelerometro GY-521 MPU6050} utile per la profilazione del guidatore, o per segnalare un incidente e per concludere un modulo \textbf{RTC real-time-clock} utile per mantenere un orario anche quando il sistema non è sotto connessione WiFi e/o è spento.

\begin{figure}[h]
  \centering
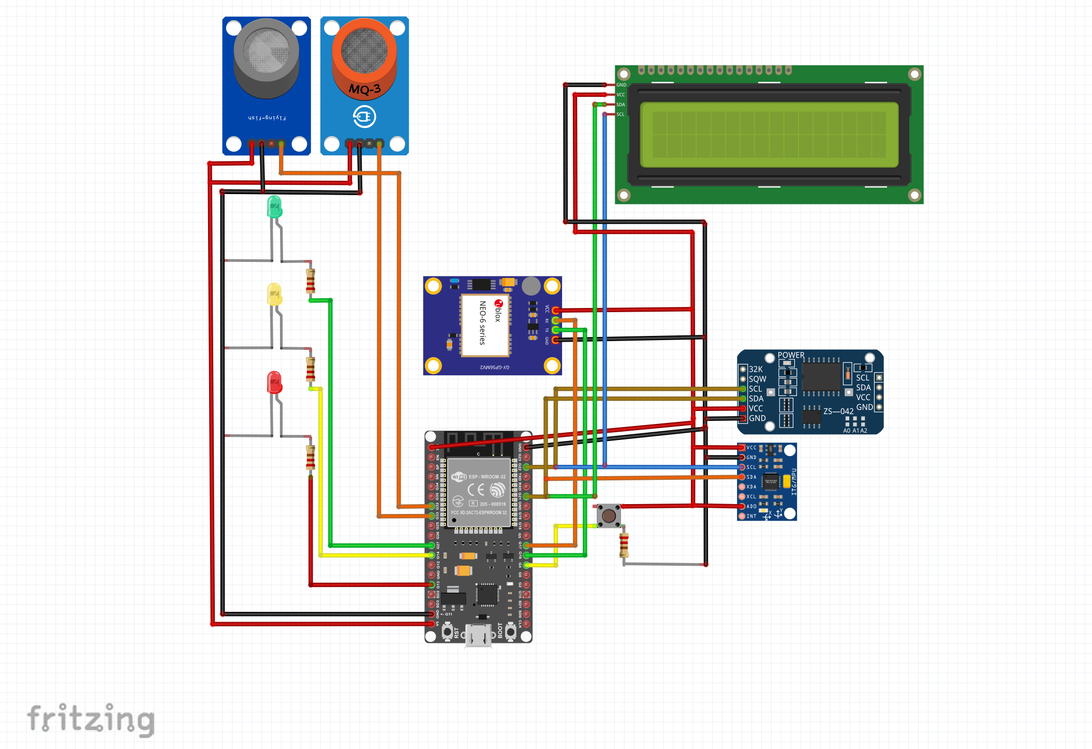
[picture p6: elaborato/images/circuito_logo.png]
  
  \caption{Schema di connessione dei vari componenti hardware della black box}
  \label{fig:schemaCircuito}
\end{figure}

\subsection{Software e librerie utilizzate}
Il codice è stato sviluppato sull'Arduino IDE, una piattaforma open source che rende semplice scrivere codice e caricarlo direttamente nelle varie board scelte all'interno di un'apposita sezione. Il linguaggio di programmazione utilizzato all'interno dell'IDE si chiama ``Arduino programming language", la sintassi è molto simile al linguaggio C o a Java, ma i costrutti più complessi come puntatori o la programmazione orientata agli oggetti vengono messi in secondo piano \cite{sistemiEmbeddedAtrent}. Oltre a fornire i costrutti standard di un linguaggio imperativo, dato il contesto applicativo dei sistemi di controllo (sensoristica e attuatoristica), offre funzionalità legate alla gestione dei segnali: I/O digitale e analogico, interrupt su eventi hardware e accesso al clock (inteso proprio come tempo trascorso dall'accensione).

Le librerie utilizzate per lo sviluppo del progetto si possono divedere in tre categorie:

\begin{itemize}
    \item Le librerie dedicate all'interazione con i vari sensori, ad esempio \textbf{TinyGPSPlus.h} per il GPS, \textbf{Adafruit\_MPU6050.h} per l'accelerometro, \textbf{LiquidCrystal\_I2C.h} per il display, e \textbf{time.h, sntp.h, RTClib.h} per l'RTC.
    \item Le librerie dedicate alla gestione interna del filesystem, ad esempio \textbf{LittleFS.h} per la gestione del filesystem e \textbf{sqlite3.h} per la creazione di database e interazione con essi.
    \item Le librerie dedicate alla comunicazione con i componenti esterni, ad esempio \textbf{``BluetoothSerial.h"} e \textbf{``ELMduino.h"} che consentono la comunicazione bluetooth tra esp32 e lettore scanner OBD.
\end{itemize}

\section{Scelte progettuali}
\subsection{Filesystem}
Nel filesystem dell'esp32 viene creato un database (dati.db) all'interno del quale sono presenti 5 tabelle utili per la gestione di tutti gli eventi previsti dalla black-box. Per interagire con il db viene utilizzata SQLite, una libreria scritta in linguaggio C che implementa un motore di database SQL piccolo, veloce, autonomo, ad alta affidabilità e completo. SQLite è uno tra i motori di database più utilizzati nel mondo embedded: esso è integrato in tutti i telefoni cellulari, nella maggior parte dei computer ed in innumerevoli altre applicazioni utilizzate ogni giorno \cite{sqliteWhentoUse}. SQLite è particolarmente adatto per l'uso in telefoni cellulari, set-top box, televisori, console di gioco, fotocamere, orologi, elettrodomestici da cucina, termostati, automobili, macchine utensili, aeroplani, sensori remoti, droni, dispositivi medici e robot: \textbf{``internet of things"}.
Di seguito verranno presentate le tabelle di memorizzazione dati dell'intero sistema con qualche esempio di dato memorizzato:
% \todo{AT: avrei messo (anche o solo) uno schema ER} -> aggiunto schema ER dopo la presentazione delle tabelle

\paragraph{Tabella t1}
\begin{table}[h!]
  \centering 
  \begin{adjustbox}{max width=\textwidth}
    \begin{tabular}{|c|c|c|c|c|c|c|}
      \hline
      \textbf{nomeSensore} & \textbf{valore} & \textbf{tipoDato} & \textbf{unitàMisura} & \textbf{timestamp} & \textbf{synchronised} & \textbf{priority} \\
      \hline
      TEXT & TEXT & TEXT & TEXT & INTEGER (seconds since epoch) & INTEGER (boolean) & INTEGER \\
      \hline
      ``Liquido raffreddamento" & ``98" & ``INTEGER" & ``°C" & 1715786497 & 0 & 3 \\
      \hline
      ``Voltaggio batteria" & ``12.3" & ``FLOAT" & ``Volt (V)" & 1715269497 & 1 & 8 \\
      \hline
    \end{tabular}
  \end{adjustbox}
  \caption{Tabella ``t1" dati relativi al monitoraggio del veicolo}
  \label{tab:t1 monitoraggio}
\end{table}
Il campo \textbf{timestamp} indica il numero di secondi trascorsi dall'epoc (01/01/1970), e fa riferimento al momento esatto in cui il dato è stato memorizzato.

\paragraph{Tabella t2}
\begin{table}[h!]
  \centering 
  \begin{adjustbox}{max width=\textwidth}
    \begin{tabular}{|c|c|c|c|c|c|c|}
      \hline
      \textbf{nomeSensore} & \textbf{tempoStorage} & \textbf{variabile} & \textbf{fattIncr} & \textbf{soglia} & \textbf{tMin} & \textbf{tMax} \\
      \hline
      TEXT & INTEGER & INTEGER & INTEGER & INTEGER & INTEGER & INTEGER \\
      \hline
      ``Olio motore temp" & 45 & 1 & 15 & 20 & 45 & 600 \\
      \hline
      ``Coordinate GPS" & 30 & 0 & NULL & NULL & NULL & NULL \\
      \hline
    \end{tabular}
  \end{adjustbox}
  \caption{Tabella ``t2" tempo di campionamento}
  \label{tab:t2 campionamento}
\end{table}
Il campo \textbf{tempoStorage} indica ogni quanto memorizzare il valore, espresso in secondi, \textbf{variabile} indica se il tempo di storage può cambiare, \textbf{fattIncr} dice di quanto aumentare o diminuire il tempoStorage, \textbf{soglia} delimita se i dati campionati sono omogenei, ovvero minori di essa, oppure eterogenei, maggiori di essa, infine \textbf{tMin} e \textbf{tMax} sono i corrispettivi upper e lower bound per il tempo di storage.

\textbf{Logica del tempo di campionamento:} se dopo una serie di letture (n ad esempio) i dati hanno una bassa deviazione standard, ovvero sono molto simili tra di loro, memorizzo i dati del veicolo con una frequenza minore, aumentando il tempo di storage di un certo fattore, presente nella tabella di campionamento (\textbf{fattIncr}). Se la deviazione standard è alta, significa che i dati sono abbastanza differenti tra di loro ed è necessario monitorarli con una frequenza maggiore. Naturalmente, vengono posti dei lower e upper bound per il tempo di memorizzazione entro i quali il tempo stesso può variare. Questo approccio è adottato per ottimizzare la registrazione dei dati di monitoraggio, poiché lo spazio di memoria disponibile è limitato.

\paragraph{Tabella t3}
\begin{table}[h!]
  \centering 
  \begin{adjustbox}{max width=\textwidth}
    \begin{tabular}{|c|c|c|c|}
      \hline
      \textbf{data} & \textbf{voto} & \textbf{lastStorage} & \textbf{synchronised} \\
      \hline
      TEXT & TEXT & INTEGER & INTEGER \\
      \hline
      ``2024-03-10 12:00:00" & ``0.99" & 1715786497 & 1 \\
      \hline
      ``2024-07-07 17:56:20" & ``0.53" & 1815786497 & 0 \\
      \hline
    \end{tabular}
  \end{adjustbox}
  \caption{Tabella ``t3" profilazione guida}
  \label{tab:t3 profilazione}
\end{table}
Il campo \textbf{lastStorage} indica il momento in cui è stato memorizzato il voto inteso come numero di secondi trascorsi dall'epoc.

\paragraph{Tabella t4}
\begin{table}[h!]
  \centering 
  \begin{adjustbox}{max width=\textwidth}
    \begin{tabular}{|c|c|c|}
      \hline
      \textbf{problema} & \textbf{data} & \textbf{synchronised} \\
      \hline
      TEXT & TEXT & INTEGER \\
      \hline
      ``Alcool" & ``2024-07-07 17:56:20" & 1 \\
      \hline
      ``Gas nell'abitacolo" & ``2024-07-24 14:40:34" & 0   \\
      \hline
    \end{tabular}
  \end{adjustbox}
  \caption{Tabella ``t4" allarmi critici}
  \label{tab:t4 allarmi critici}
\end{table}

\paragraph{Tabella t5}
\begin{table}[h!]
  \centering 
  \begin{adjustbox}{max width=\textwidth}
    \begin{tabular}{|c|c|c|c|c|}
      \hline
      \textbf{problema} & \textbf{rilevamenti} & \textbf{soglia} & \textbf{daMandare} & \textbf{synchronised} \\
      \hline
      TEXT & INTEGER & INTEGER & INTEGER & INTEGER \\
      \hline
      ``Fumo" & 3 & 3 & 1 & 0 \\
      \hline
      ``Fuori range GPS" & 0 & 5 & 0 & 0 \\
      \hline
    \end{tabular}
  \end{adjustbox}
  \caption{Tabella ``t5" allarmi meno critici}
  \label{tab:t5 allarmi meno critici}
\end{table}
Il campo \textbf{soglia} indica il numero massimo di rilevamenti per ciascun tipo di problema, se il sistema black-box continua a rilevare il problema e la soglia viene superata, allora viene aggiornato il campo \textbf{daMandare}, indicante che l'informazione deve arrivare al server remoto.

\newpage

\begin{figure}[h]
  \centering
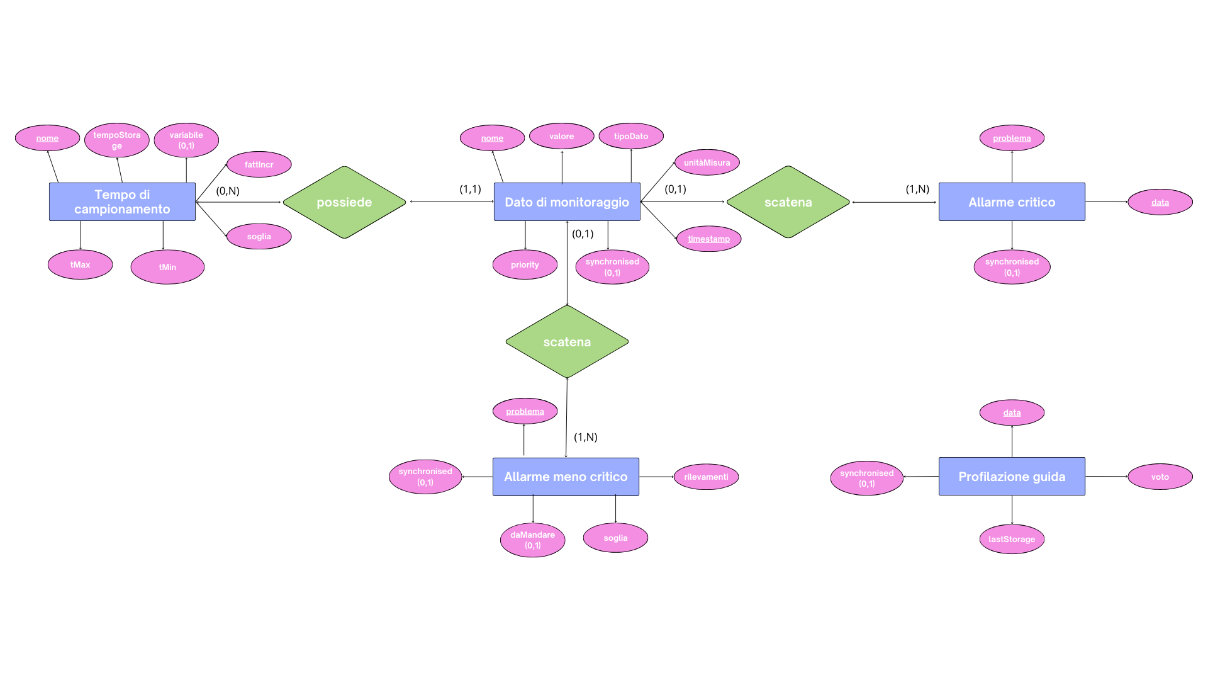
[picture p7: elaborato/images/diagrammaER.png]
  
  \caption{Diagramma entità-relazione (ER)}
  \label{fig:diagrammaER}
\end{figure}

\newpage

\subsection{Sincronizzazione}
\label{sec:Sincronizzazione}
La black-box è progettata per registrare dati in assenza di connessione Wi-Fi, appena viene rilevata la presenza di una rete, il Wi-Fi di casa ad esempio, essi vengono sincronizzati con il server remoto e vengono aggiornati i campi \textbf{synchronised} delle tabelle in modo tale da non inviare al server remoto dati duplicati e per poter gestire al meglio l'uso dello spazio di memoria all'interno del filesystem, eliminando i dati già sincronizzati. 
L'unica tabella che non presenta il campo synchronised è quella relativa al tempo di campionamento, utilizzata come tabella di configurazione per la gestione dei tempi di storage relativi ai dati di monitoraggio.

\section{Comunicazioni e trasmissione dati}
\subsection{Protocollo di comunicazione all'interno del veicolo}
I protocolli di comunicazione utilizzati nell'automotive governano il \textbf{trasferimento dei pacchetti} lungo la rete del veicolo. Varie sottoreti e centinaia di sensori comunicano su sistemi a bus, inviando messaggi che controllano il comportamento del veicolo e le informazioni che la rete ``conosce" in ogni dato momento.
Le comunicazioni critiche per il veicolo, ad esempio la gestione dei giri del motore (RPM) e dei freni, viaggiano su linee di bus ad alta velocità, mentre quelle non critiche, come il blocco delle porte e il controllo A/C, viaggiano su linee di bus a media o bassa velocità.
\paragraph{Protocollo CAN BUS} CAN (Control Area Network) è un protocollo di comunicazione utilizzato nel settore manifatturiero e automobilistico. I veicoli più recenti sono pieni di piccoli sistemi embedded e di unità di controllo elettronico (ECU) che comunicano tra di loro utilizzando il protocollo CAN. Questo protocollo è divenuto uno standard delle vetture e dei piccoli autocarri statunitensi dal 1996, ma è stato reso obbligatorio solo nel 2008 (nel 2001 per i veicoli europei) \cite{manualeHacker}. 

\newpage

CAN utilizza due cavi a doppino intrecciato: \textbf{CAN high} (CANH) e \textbf{CAN low} (CANL) e usa un \textbf{segnale} di tipo \textbf{differenziale}, il che significa che, quando arriva un segnale, CAN aumenta la tensione su una linea e riduce quella dell'altra in misura uguale, vedi figura \ref{fig:segnaleDiffCAN}. Il segnale differenziale è utilizzato in ambienti che debbono essere fault tolerant per quanto riguarda il rumore, come nei sistemi automobilistici e nella manifattura.

\vspace{0.2cm}

\begin{figure}[h]
  \centering
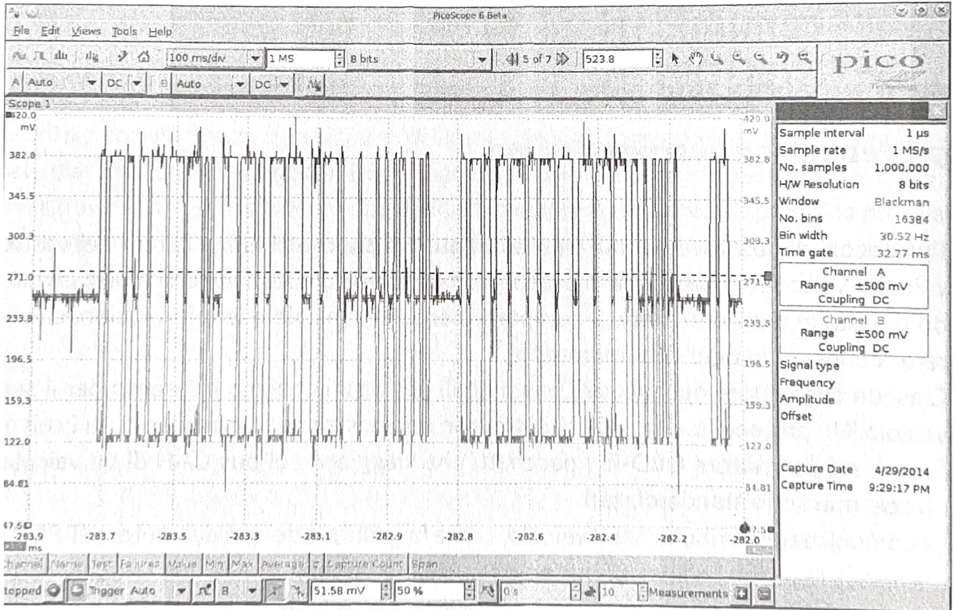
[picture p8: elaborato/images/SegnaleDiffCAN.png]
  
  \caption{Segnale differenziale CAN\protect\footnotemark (fonte: libro Il manuale dell'hacker di automobili di Chris Evans)}
  \label{fig:segnaleDiffCAN}
\end{figure}

La figura \ref{fig:segnaleDiffCAN} mostra un segnale catturato con un PicoScope, che ascolta sia CANH (linee più scure nella parte superiore del grafico) sia CANL (linee più chiare nella parte inferiore del grafico). Si può osservare che, quando viene trasmesso un bit sul bus CAN, il segnale diffonde simultaneamente 1V in più e in meno. I sensori, gli attuatori e le ECU hanno un ricetrasmettitore che verifica che entrambi i segnali siano innescati: se non lo sono, rifiuta i pacchetti come rumore. 

\begin{figure}[h]
  \centering
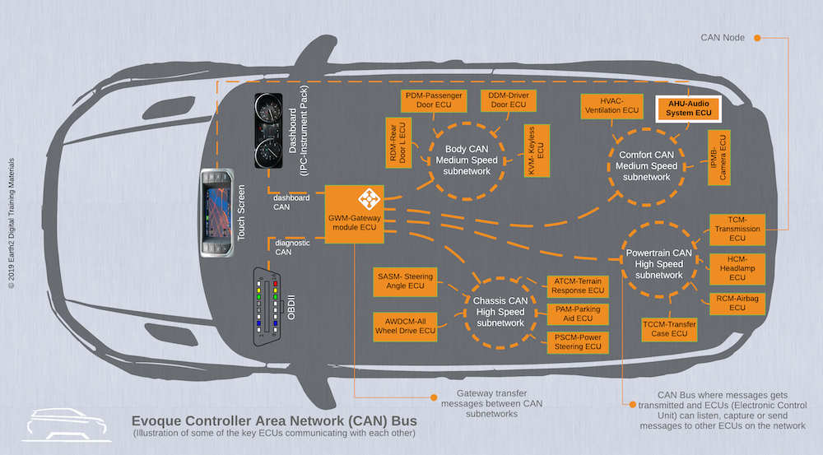
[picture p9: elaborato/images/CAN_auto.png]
  
  \caption{Protocollo CAN BUS all'interno di un'autovettura\protect\footnotemark (fonte: Giuseppe Caccavale)}
  \label{fig:Protocallo CAN-BUS}
\end{figure}%\todo{AT: anche qui manca fonte nella caption, verifica tutte le figure}
\footnotetext{Presa da: \url{https://farelettronica.it/web/app/uploads/2022/04/02-controller-area-network-ecu-evoque-adam-ali-small.png}}

\paragraph{Il connettore OBD} Molti veicoli sono dotati di un connettore \textbf{OBD-II}, detto anche connettore del collegamento diagnostico (DLC, Diagnostic Link Connector), che comunica con la rete interna del veicolo. Solitamente questo connettore si trova sotto il piantone dello sterzo o nascosto da qualche parte nel cruscotto in una posizione comunque accessibile.
La tensione a riposo dei cavi CAN è di 2.5V, quando arriva un segnale, si sommerà o sottrarrà 1V alla tensione a riposo  (3.5V o 1.5V). I fili CAN attraversano il veicolo, collegano le ECU e altri sensori e sono sempre in coppia. Le connessioni CAN high e CAN low sono presenti sui pin 6 e 14 del connettore OBD-II, come illustrato nella figura sottostante \ref{fig:Connettore OBD}. \cite{manualeHacker}

\begin{figure}[h]
  \centering
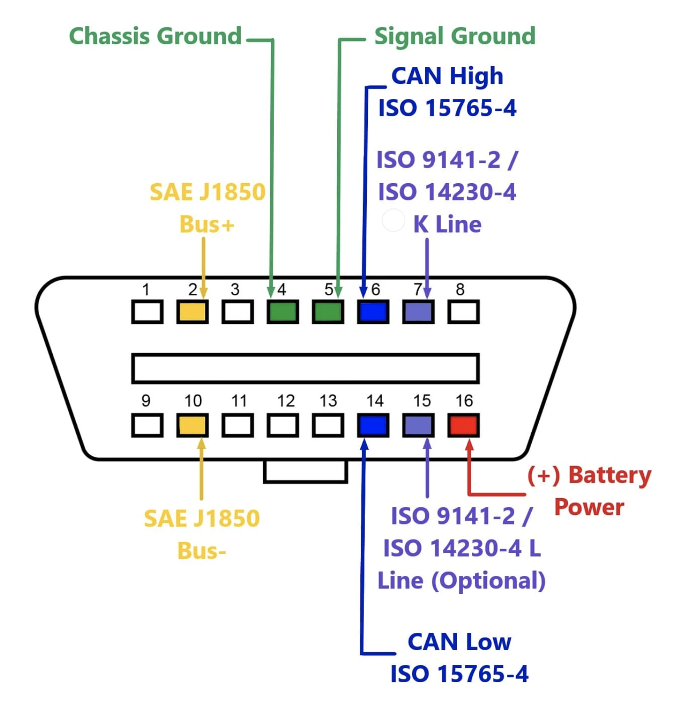
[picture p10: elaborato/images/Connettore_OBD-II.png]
  
  \caption{Pin dei cavi CAN sul connettore OBD-II\protect\footnotemark (fonte: Flexihub)}
  \label{fig:Connettore OBD}
\end{figure}
\footnotetext{Presa da: \url{https://www.flexihub.com/images/upload/flexihub/articles/diagnostics/pinout_explanation.jpg}}

\paragraph{Struttura dei pacchetti del bus CAN}
Vi sono due tipi di pacchetti CAN: 
\textbf{standard} ed \textbf{estesi}. I pacchetti estesi sono come quelli standard, semplicemente hanno uno spazio maggiore per conservare l'ID. \textbf{Pacchetti standard:} Ogni pacchetto di bus CAN contiene quattro elementi fondamentali:
\begin{itemize}
    \item \textbf{L'ID di arbitraggio} (arbitration ID) è un messaggio broadcast che indica l'ID del dispositivo che cerca di comunicare, anche se ogni dispositivo può inviare più ID di arbitraggio. Se sul bus vengono inviati due pacchetti CAN contemporaneamente, vince quello con l'ID di arbitraggio più basso.
    \item \textbf{IDE}, estensione dell'identificatore (Identifier Extension). Questo bit è sempre 0 per i pacchetti CAN standard.
    \item \textbf{DLC}, codice della lunghezza dei dati (Data Length Code) Questa è la dimensione dei dati che varia da 0 a 8 byte.
    \item \textbf{Dati} Questi sono i dati in senso stretto. Le dimensioni massime dei dati veicolati da un pacchetto standard del bus CAN è di 8 byte, ma alcuni sistemi forzano le dimensioni sempre a 8 byte, ``imbottendo" il pacchetto.
\end{itemize}

\begin{figure}[h]
  \centering
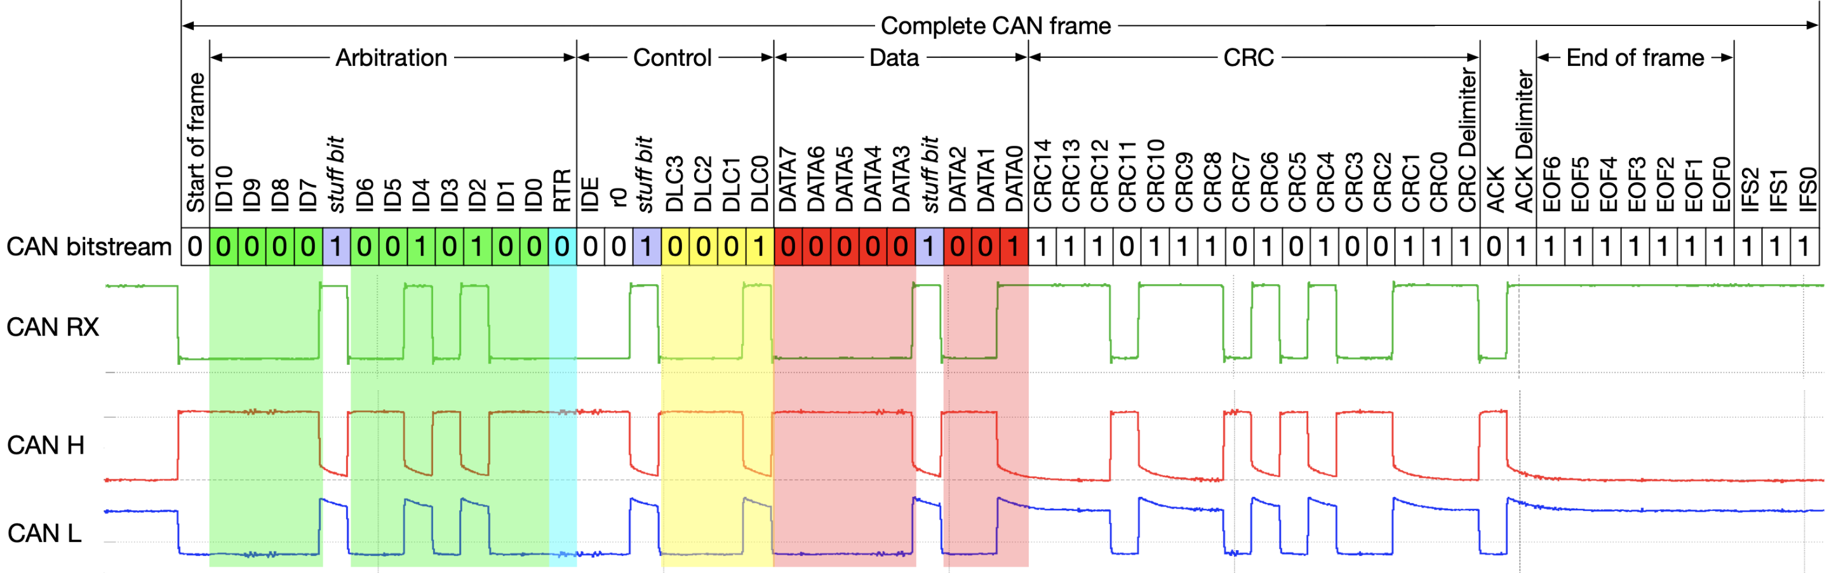
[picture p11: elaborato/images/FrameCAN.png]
  
  \caption{Formato dei pacchetti CAN standard\protect\footnotemark (fonte: Wikipedia)}
  \label{fig:pacchettoCAN}
\end{figure}
\footnotetext{Presa da: \url{https://upload.wikimedia.org/wikipedia/commons/5/54/CAN-bus-frame-with-stuff-bit-and-correct-CRC.png}}

Poiché i pacchetti del bus CAN sono di tipo broadcast, tutti i controller sulla stessa rete vedono tutti i pacchetti. 

\textbf{Pacchetti estesi:}
I pacchetti estesi sono come quelli standard, tranne che possono essere concatenati fra loro per creare ID più lunghi. I pacchetti estesi sono fatti in modo da adattarsi alla formattazione CAN standard per mantenere la compatibilità a ritroso, cosicchè se un sensore non ha il supporto per i pacchetti estesi, non si guasterà se un altro dispositivo trasmette pacchetti CAN estesi sulla stessa rete. I pacchetti standard e quelli estesi si differenziano anche per l'uso dei flag. Se esaminati i pacchetti estesi in un dump di rete, si vedrà che, a differenza di quelli standard, usano un flag \textbf{SSR} (Substitute remote request) anzichè \textbf{RTR} (Remote transmission request), con SSR impostato al valore 1, per separare la prima parte del pacchetto con l'Identifier extension bit (IDE). I pacchetti estesi avranno il campo IDE impostato al valore 1 ed identificatori a 29 bit, 18 bit presenti subito dopo l'IDE e gli 11 bit standard presenti nella prima parte del pacchetto.

\subsection{OBD scanner - esp32}
\label{sec:capitolo432}
Per leggere i messaggi presenti all'interno della rete CAN BUS è necessario un lettore OBD-II in grado di connettersi con il corrispettivo connettore OBD presente all'interno del veicolo e di trasmettere dati via \textbf{Bluetooth} ad un apparecchio esterno, in questo caso l'esp32. Per leggere e decifrare i messaggi provenienti dalla rete CAN, è stata utilizzata una libreria ELMduino, utile per interfacciare facilmente l'esp32 con uno scanner OBD-II. Tramite questa libreria è possibile interrogare tutti i PID supportati da OBD-II per raccogliere un'ampia varietà di dati, ad esempio velocità, giri al minuto, temperatura dell'olio motore...

\begin{figure}[h]
  \centering
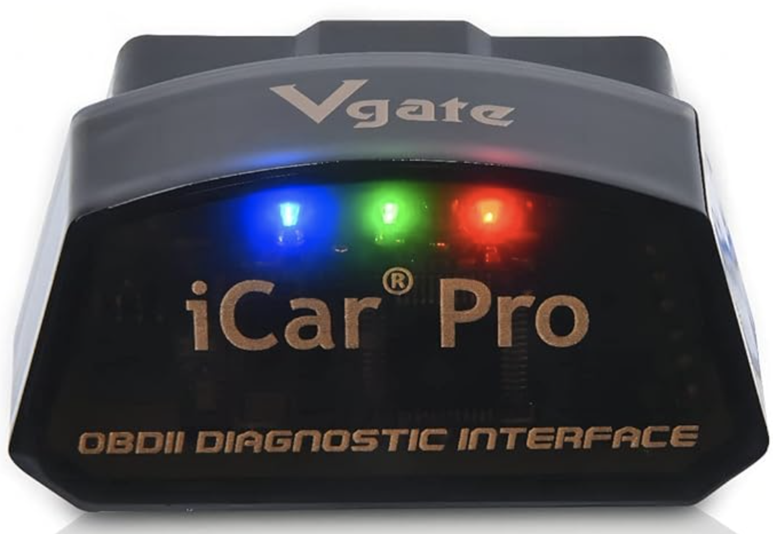
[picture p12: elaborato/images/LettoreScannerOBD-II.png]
  
  \caption{Esempio di scanner OBD-II utilizzato per il progetto\protect\footnotemark (fonte: Amazon)}
  \label{fig:scannerOBD-II}
\end{figure}
\footnotetext{Presa da: \url{https://m.media-amazon.com/images/I/51crnV3RTbL._AC_SX679_.jpg}}

\subsection{esp32 - server remoto}
Quando la black-box rileva la presenza di una connessione Internet, si collega ad un server remoto. Esso è sempre in ascolto, al fine di ricevere dati relativi al monitoraggio, alla segnalazione di allarmi e sulla profilazione del conducente. 
Nel progetto viene adoperato Netcat, un programma open source a riga di comando di comunicazione remota, utilizzabile sia col protocollo TCP sia col protocollo UDP. Lato server è necessario mettersi in ascolto per ricevere dati al momento di sincronizzazione, dopodichè è possibile redirigere l'output su di un file utilizzato appositamente per la raccolta dati. \cite{Netcat}

\chapter{Risultati ottenuti}
\section{Analisi dei risultati}
Sono state condotte analisi relative alla segnalazione di allarmi e alla profilazione guida. Le prime sono state verificate in modo tale da far sollecitare il task relativo al rilevamento della situazione anomala e verificare che venga esibito sul display il relativo avviso di pericolo, o la relativa notifica di comportamento errato, e verificato ulteriormente che al server fossero arrivate le opportune notifiche. 

\begin{figure}[h]
  \centering
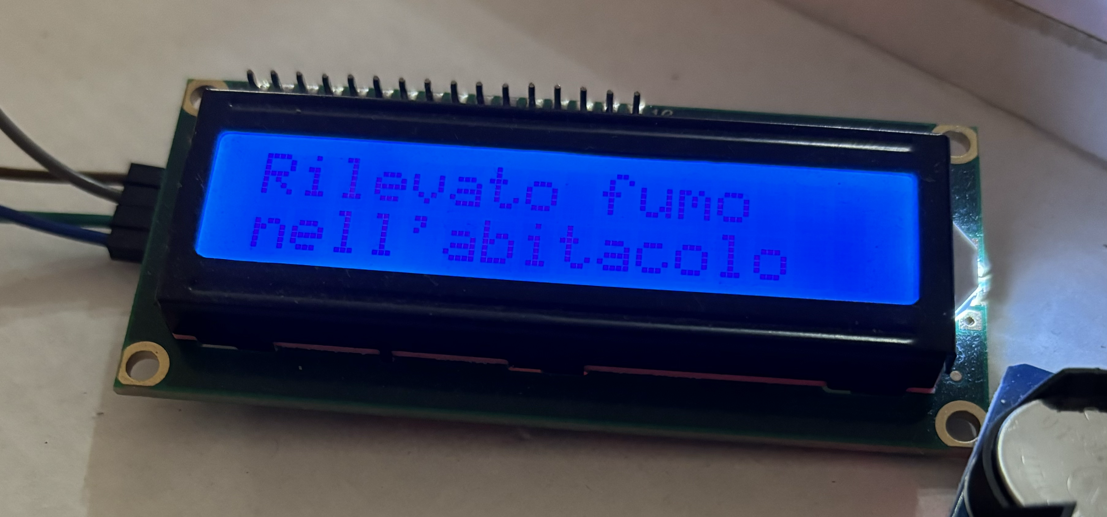
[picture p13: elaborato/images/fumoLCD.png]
  
  \caption{Display presente sulla black-box che notifica al guidatore il fatto di aver rilevato una presenza di fumo nell'abitacolo}
  \label{fig:fumoLCD}
\end{figure}

\begin{figure}[h]
  \centering
  
  \caption{Esempio di notifica ricevuta al server remoto al seguito di aver rilevato più volte la presenza di fumo nell'abitacolo}
  \label{fig:fumoServer}
\end{figure}

Per quanto riguarda la profilazione guida, sono state simulate 3 guide da 20 minuti circa ciascuna. Per ogni guida, sono stati modificati i parametri relativi alla profilazione del guidatore così da poter distinguere ciascuna di esse in 3 diverse categorie: guida \textbf{spericolata}, \textbf{intermedia},  e \textbf{moderata}. I parametri che sono stati simulati sono: accelerometria lungo i due assi x e y, i giri motore (rpm), la velocità del veicolo (kph), la posizione della valvola a farfalla e il carico motore. 

\begin{table}[h!]
  \centering 
  \begin{adjustbox}{max width=\textwidth}
    \begin{tabular}{|c|c|c|c|c|c|c|c|}
      \hline
      \textbf{Stile guida} & \textbf{acc. asse x} & \textbf{acc. asse y} & \textbf{rpm} & \textbf{kph} & \textbf{throttle} & \textbf{engine load} & \textbf{voto} \\
      \hline
      Spericolato & $[-9,9] \ \text{m/s}^2$ & $[-9,9] \ \text{m/s}^2$ & $[3000,4000] \ \text{giri/min}$ & $[0,130] \ \text{km/h}$ & $[40,90] \%$ & $[30,70] \%$  & 0.695\\
      \hline
      Intermedio & $[-7,7] \ \text{m/s}^2$ & $[-7,7] \ \text{m/s}^2$ & $[2000,3000] \ \text{giri/min}$ & $[0,130] \ \text{km/h}$ & $[30,70] \%$ & $[20,60] \%$  & 0.428\\
      \hline
      Moderato & $[-5,5] \ \text{m/s}^2$ & $[-5,5] \ \text{m/s}^2$ & $[1500,2500] \ \text{giri/min}$ & $[0,130] \ \text{km/h}$ & $[20,50] \%$ & $[10,50] \%$  & 0.328\\
      \hline
    \end{tabular}
  \end{adjustbox}
  \caption{Tabella rappresentante i range dei valori dei parametri utili alla profilazione del conducente, rappresentanti diversi stili di guida con relativa attribuzione del voto.}
  \label{tab:stili_di_guida}
\end{table}

Come ulteriore verifica relativa al corretto funzionamento dell'algoritmo di profilazione del conducente, sono stati elaborati tutti i dati relativi a tale attività da un \textbf{algoritmo esterno} scritto da un collega tesista, Giuseppe Bianchi,
% \todo{AT: metti nome e cognome, a meno che Bianchi preferisca di no, chiedigli} 
e sono stati messi a confronto i risultati finali di tale algoritmo con quello implementato all'interno della black-box. L'obiettivo dell'algoritmo esterno è quello di profilare lo stile di guida del conducente, attribuendogli un'etichettatura rappresentativa. Sono state simulate 3 guide da 20 minuti ciascuna, ognuna rappresentante uno stile di guida diverso dall'altra (sono stati usati gli stessi range di valori usati precedentemente \ref{tab:stili_di_guida}), ed è stato modificato il codice così da poter inoltrare i dati relativi alla profilazione al server remoto. I dati, ricevuti dalla black-box in formato \textbf{NDJSON} (Newline Delimited JSON), sono stati filtrati utilizzando apposite librerie in R, come \textbf{jsonlite}, un parser e generatore JSON semplice e robusto. Successivamente, i dati sono stati convertiti in un dataframe per facilitarne la manipolazione in R, quindi trasformati in formato CSV per essere utilizzati dall'algoritmo esterno. I rusultati sono stati messi a confronto con la tabella \ref{tab:stili_di_guida}.

\newpage

I grafici mostrati sotto rappresentano i tre stili di guida, ciascuno classificato dall'algoritmo esterno. 

\vspace{1cm}

\begin{figure}[h]
  \centering
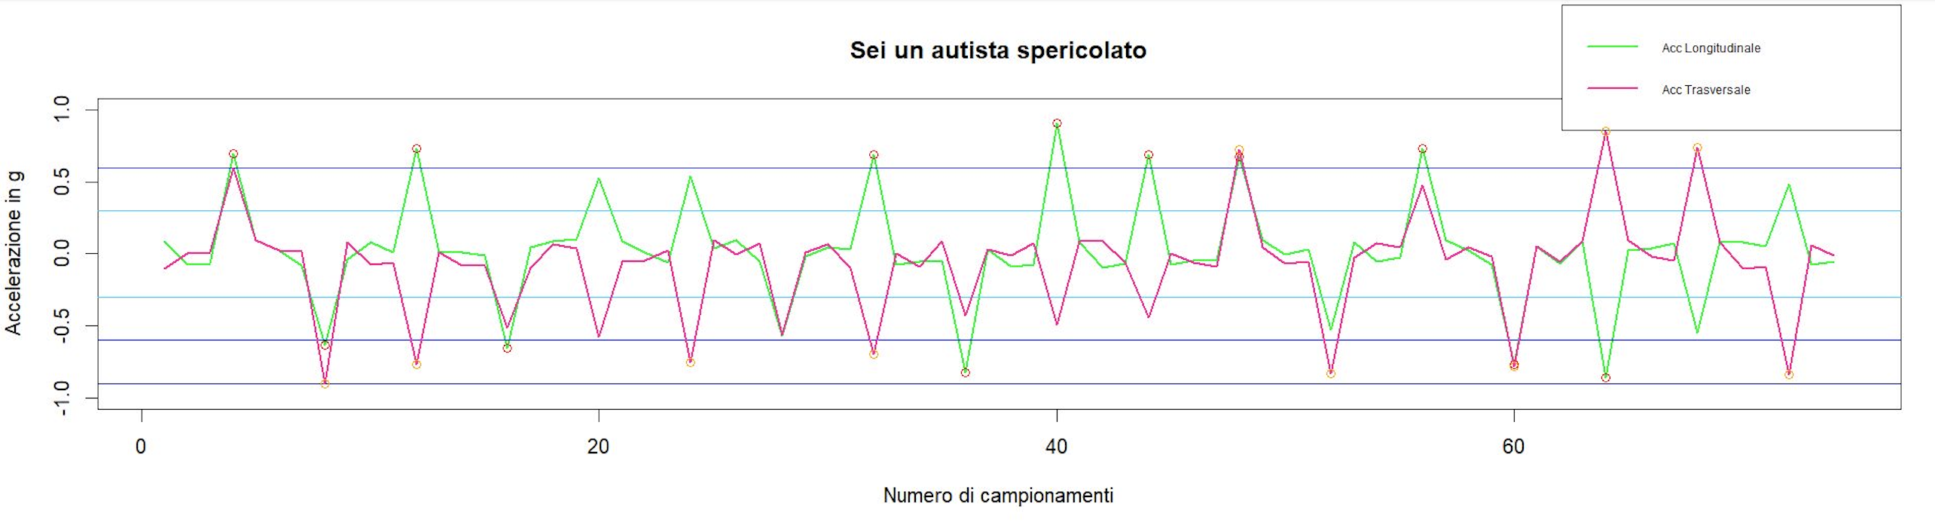
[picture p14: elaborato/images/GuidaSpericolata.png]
  
  \caption{Stile di guida spericolato}
  \label{Guida spericolata}
\end{figure}

\begin{figure}[h]
  \centering
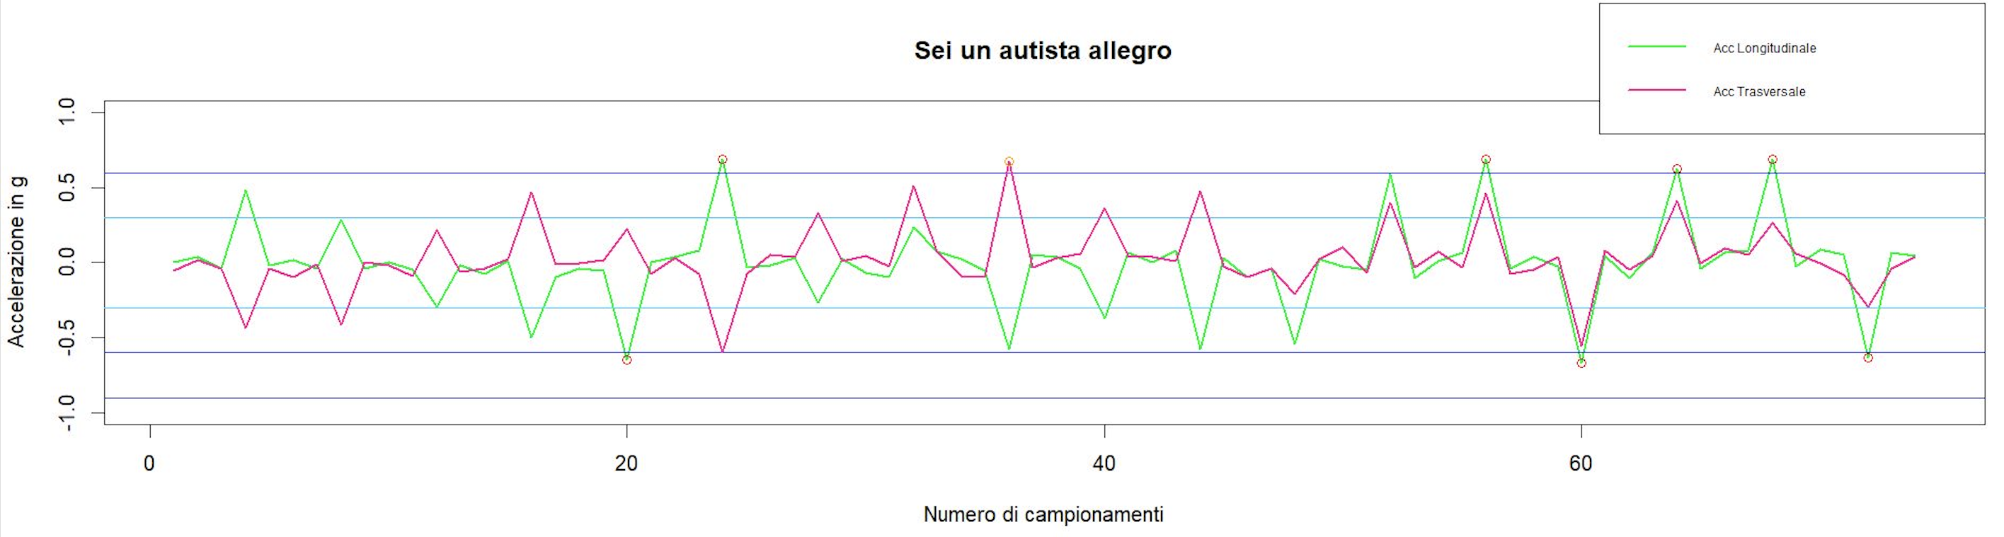
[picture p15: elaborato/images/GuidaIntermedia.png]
  
  \caption{Stile di guida intermedio}
  \label{Guida intermedia}
\end{figure}

\begin{figure}[h]
  \centering
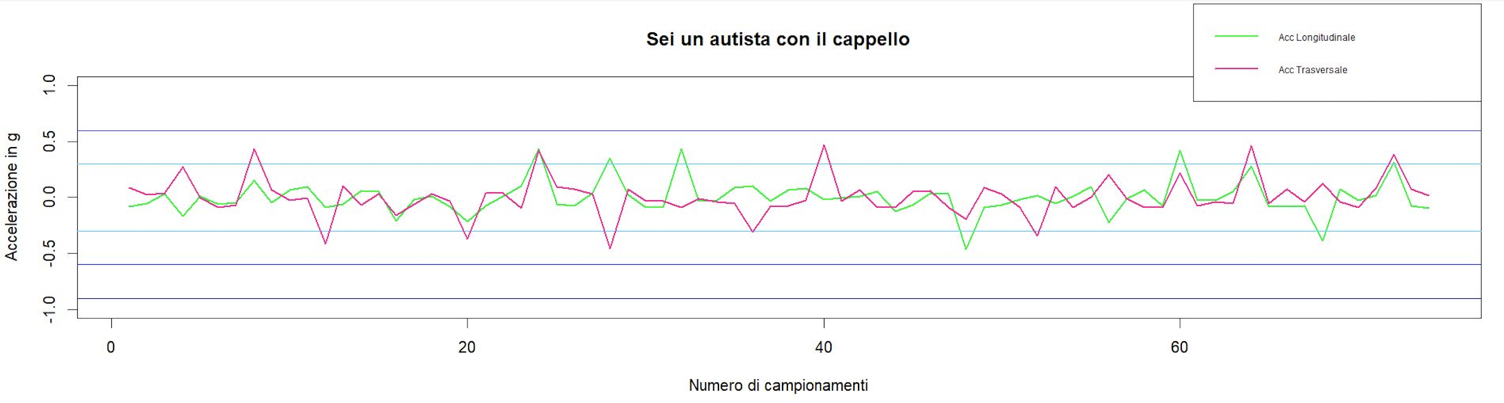
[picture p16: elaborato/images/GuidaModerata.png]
  
  \caption{Stile di guida moderato}
  \label{Guida moderata}
\end{figure}

\newpage

Osservando le tre classificazioni è possibile notare che il trend valutativo risulta essere molto simile alle valutazioni che sono state date precedentemente dall'algoritmo presente all'interno della board. 

\vspace{1cm}

Per concludere, di seguito verrà mostrato un esempio di una serie di dati di monitoraggio, segnalazione di allarmi e profilazione guida ricevuti al server a seguito di una sincronizzazione:

\begin{figure}[h]
  \centering
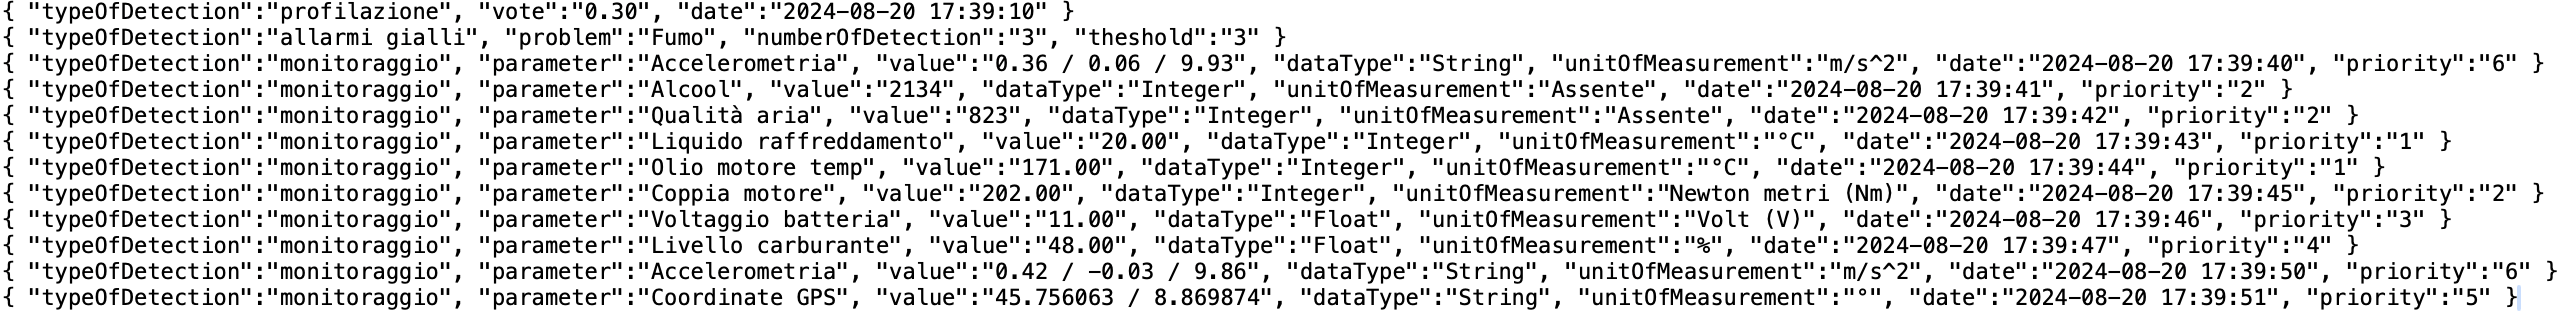
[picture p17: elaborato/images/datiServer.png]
  
  \caption{Ricezione dati lato server}
  \label{fig:datiServer}
\end{figure}

\newpage

\section{Comportamenti non implementati}
Alcuni comportamenti relativi alla segnalazione di allarmi critici e non, non sono stati implementati. Questi riguardano la gestione degli allarmi relativi al \textbf{consumo anomalo di carburante} e alla \textbf{distanza di frenata anomala} per quanto riguarda gli allarmi critici, il \textbf{rilevamento di attività di rimorchio e della presenza di fumo} per quanto riguarda invece gli allarmi meno critici. Quest'ultima funzionalità è facilmente implementabile con l'installazione di un sensore apposito che rileva la presenza di fumo nell'ambiente che lo circonda; l'implementazione delle prime tre funzionalità è stata volutamente non implementata data la complessa natura dei problemi, i quali richiedono uno studio complesso e approfondito. Questi aspetti rimangono importanti per sviluppi futuri e rappresentano punti chiave per migliorare ulteriormente il sistema.

Un altro componente non installato nel sistema attuale è il \textbf{modulo GSM con relativa antenna}, che permette la comunicazione con il server remoto della centrale operativa indipendentemente dalla disponibilità di una rete WiFi.
L'installazione del modulo GSM può essere facilmente eseguito seguendo due approcci: 

\begin{itemize}
    \item \textbf{Modulo separato}: un modulo GSM con relativa antenna può essere facilmente aggiunto al sistema esistente. Questi moduli sono ampiamente disponibili e possono essere integrati con l'esp attraverso interfacce standard, vedi figura  \ref{fig:modulo_gsm}.
    \item \textbf{Modulo integrato}: esistono versioni dell'esp32 che includono un modulo GSM integrato, semplificando ulteriormente l'implementazione di questa funzionalità senza la necessità di componenti aggiuntivi, vedi figura \ref{fig:esp32_gsm}.
\end{itemize}

\begin{figure}[h]
  \centering
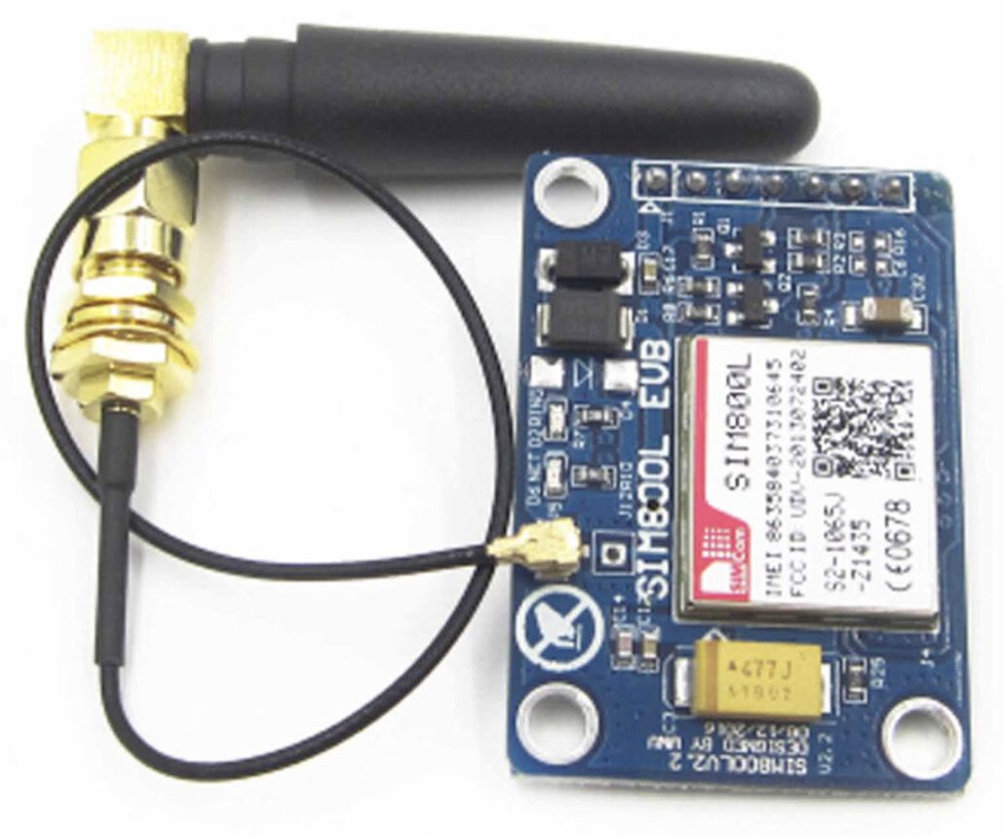
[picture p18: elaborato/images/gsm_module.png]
  
  \caption{Modulo GSM da integrare\protect\footnotemark (fonte: ebay)}
  \label{fig:modulo_gsm}
\end{figure}
\footnotetext{Presa da: \url{https://i.ebayimg.com/images/g/~dEAAOSwmwdhZkO7/s-l1200.jpg}}

\begin{figure}[h]
  \centering
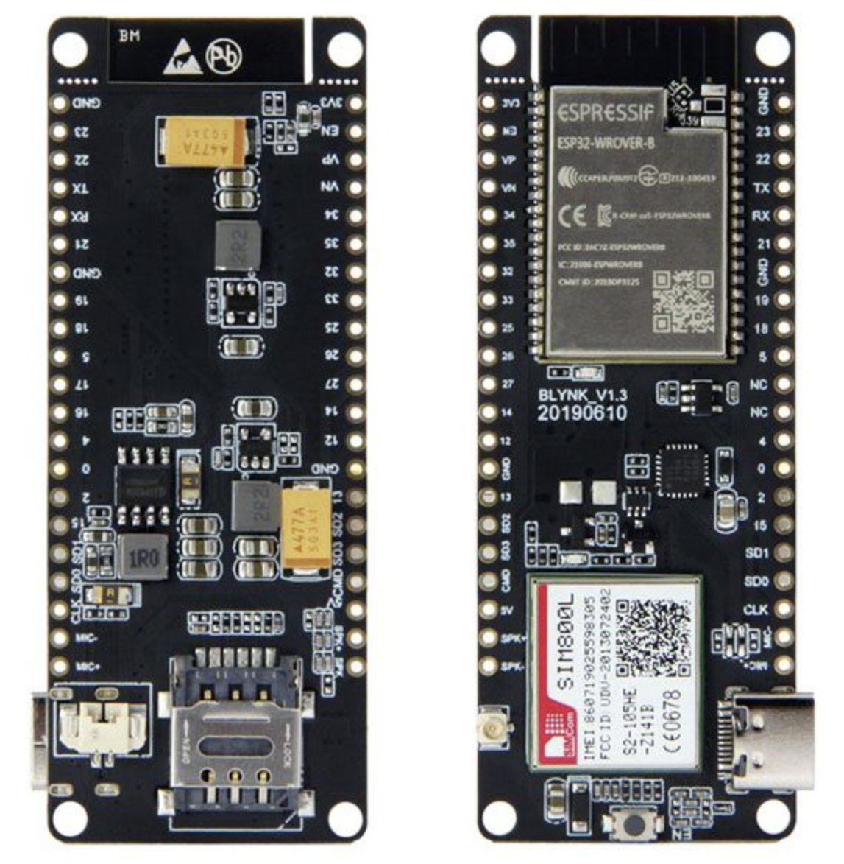
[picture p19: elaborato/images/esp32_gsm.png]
  
  \caption{Esp32 SIM800L\protect\footnotemark (fonte: futura group progetti)}
  \label{fig:esp32_gsm}
\end{figure}
\footnotetext{Presa da: \url{https://futuranet.it/wp-content/uploads/2021/02/1606-HR1761.jpg}}

\chapter{Conclusioni}
\section{Problemi aperti}
\paragraph{Problema di decremento dello spazio di storage}
Nel sistema black-box sono presenti due task che hanno il compito di ripulire la memoria del microcontrollore, vedi paragrafo \ref{sec:Sincronizzazione}, uno di routine che elimina i record già sincronizzati ed uno che elimina i record se viene superata una soglia massima di occupazione del filesystem (90\%), eliminando la metà dei record di monitoraggio meno recenti. Il problema riscontrato risale a quest'ultimo task. Lo spazio di storage man mano che vengono memorizzati record aumenta in modo corretto, tuttavia a seguito delle operazioni di pulizia dei record effettuate dal task di routine che rimuove dalla tabella di monitoraggio i record già sincronizzati, lo spazio di storage non diminuisce come previsto. Tale problema persiste anche dopo aver tentato di utilizzare un particolare comando \textbf{VACUUM}, che solitamente dovrebbe riorganizzare il database e liberare lo spazio inutilizzato. 
Tale task di pulizia, che riguarda il monitoraggio della capacità di memoria del filesystem e l'eliminazione dei record meno recenti, non è stato implementato nel codice.

\section{Sviluppi futuri}
\subsection{Memoria}
Negli sviluppi futuri del progretto, un'area di miglioramento fondamentale è l'integrazione di una memoria esterna con la board. Questa aggiunta apporterà significativi vantaggi operativi e funzionali, suddivisibili in due principali categorie: l'aumento dello spazio di storage per il monitoraggio del veicolo e la capacità di caricare e utilizzare mappe stradali per verificare il rispetto dei limiti di velocità.

\begin{figure}[h]
  \centering
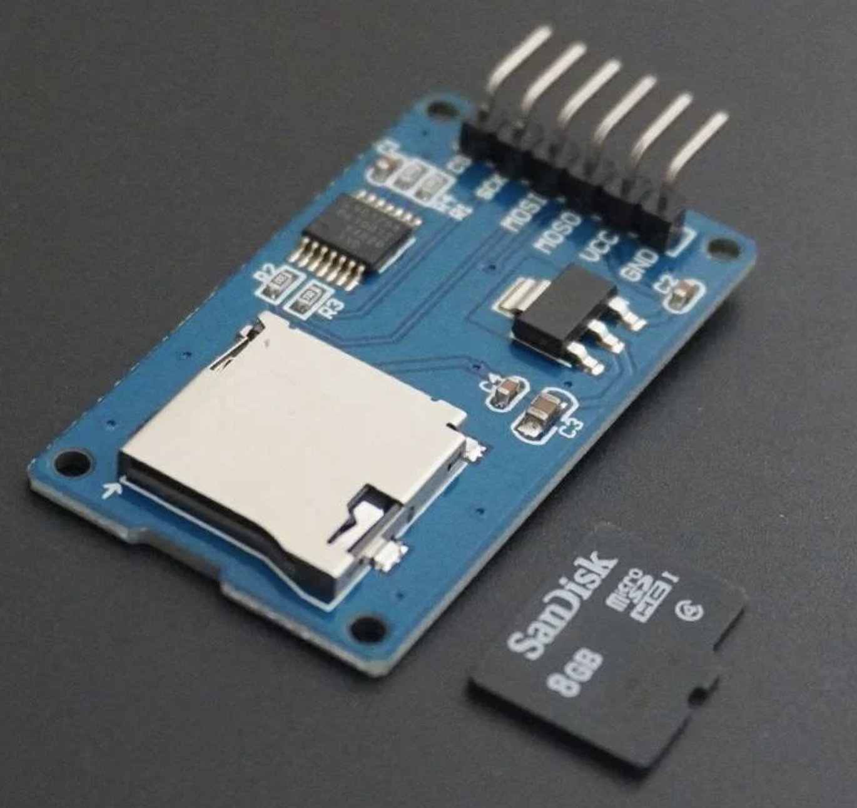
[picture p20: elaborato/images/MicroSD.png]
  
  \caption{Micro SD card\protect\footnotemark (fonte: electronicWings)}
  \label{fig:MicroSD}
\end{figure}
\footnotetext{Presa da: \url{https://www.electronicwings.com/storage/PlatformSection/TopicContent/452/description/MicroSD.jpg}}

\paragraph{Maggiore spazio di storage per il monitoraggio del veicolo} 
Uno dei limiti attuali dell'esp32 è la sua capacità di storage relativamente limitata (4MB), che può rappresentare un ostacolo nel contesto del monitoraggio continuo dei dati del veicolo. L'integrazione di una memoria esterna, come una scheda microSD o modulo di memoria flash, è in grado di aumentare notevolmente la quantità di dati che possono essere registrati e memorizzati. Questo incremento di capacità di storage consente di:

\begin{itemize}
    \item \textbf{Monitoraggio continuo}: registrare dati continuamente per periodi più estesi senza preoccuparsi di esaurire lo spazio disponibile.
    \item \textbf{Sincronizzazione rara con il server remoto}: ridurre la necessità di sincronizzare frequentemente i dati raccolti con un server centrale. I dati possono essere raccolti e conservati localmente per lunghi periodi e sincronizzati solo quando una rete WiFi stabile è disponibile. Attualmente il sistema prevede la sincronizzazione una volta al giorno, anche se è possibile sincronizzare più raramente.
\end{itemize}

\paragraph{Caricamento di mappe per il rispetto dei limiti di velocità} 
Un'altra funzionalità utile per la profilazione e che potrebbe essere implementata con l'aggiunta di una memoria esterna, è la possibilità di caricare e gestire mappe stradali. Questa capacità può essere adoperata per monitorare il rispetto dei limiti di velocità del veicolo in diverse aree geografiche. I vantaggi includono:

\begin{itemize}
    \item \textbf{Verifica del rispetto dei limiti di velocità}: Utilizzando mappe che includono informazioni sui limiti di velocità in zone urbane, extraurbane. e autostradali, il sistema può monitorare in tempo reale se il veicolo rispetta i limiti imposti in ogni tratto stradale.
    \item \textbf{Sicurezza stradale}: aumentare la sicurezza stradale, informando il conducente in caso di superamento dei limiti di velocità. 
\end{itemize}

\subsection{Profilazione conducente lato server remoto} % \todo{AT: tutta questa parte è solo teorica, non c'è nulla di effettivamente applicato al tuo caso?} -> Esatto è teorica, l'ho scritta perchè ci tenevo a mettere in evidenza che se non si è soddisfatti dell'algoritmo di profilazione interno della black-box, con facilità si può profilare il cliente con tecniche già esistenti di ML (ho fatto un riassunto delle tecniche più comuni che ho letto nei vari paper di profilazione)
Per concludere tale studio possiamo affiancare alla capacità della board di valutazione del guidatore, tecniche di Machine Learning relative sia all'apprendimento supervisionato che non supervisionato, consentendoci di esaminare più approfonditamente la natura della nostra flotta. In questo contesto, ci si concentrerà su due principali tecniche di Machine Learning: la \textbf{classificazione} e il \textbf{clustering}. La classificazione permette di assegnare ai guidatori delle etichette, come ad esempio 'prudente' piuttosto che 'negligente', in base ai loro comportamenti al volante, mentre il clustering consente di raggruppare i guidatori in base a similitudini nel comportamento di guida. \cite{wiki:Apprendimento_automatico}

\vspace{0.5cm}

\paragraph{Machine Learning nell'analisi dei guidatori: applicazioni nel nostro contesto}
Una volta processati i dati relativi all'analisi di profilazione del guidatore, essi possono essere inviati ad un server remoto. Dopodichè, è possibile usare varie tecniche di machine learning di apprendimento supervisionato, ad esempio la \textbf{classificazione}, o di apprendimento non supervisionato ad esempio il \textbf{clustering}, per assegnare ai clienti dell'autonoleggio una certa etichetta di classificazione o raggrupparli in cluster in modo tale da poter osservare un generale comportamento della flotta.

\newpage

Per concludere, lo schema rappresentato a figura \ref{fig:ProfilazioneML} indica che con la black-box è possibile sfruttare la capacità valutativa della board, la quale è in grado di generare uno score del guidatore e di giudicarlo in base a questo, la possibilità di classificarlo utilizzando tecniche di machine learning o la possibilità di utilizzare entrambe le tecniche per avere un quadro completo relativo al suo stile di guida.

\vspace{0.5cm}

\begin{figure}[h]
\centering
\scalebox{0.7}{ % Modifica il fattore di scala (0.8 in questo caso)
\begin{tikzpicture}[node distance=2cm]

% Definizione dei nodi
\node (ecu) [process] {ECU};
\node (obd) [process, below of=ecu] {OBD-II adapter};
\node (profiling) [process, below of=obd] {Driver profiling};
\node (score) [process, below of=profiling, xshift=-3.5cm] {Score obtained by board};
\node (ml) [process, below of=profiling, xshift=3.5cm] {Machine Learning technique};

% Connessione tra i nodi
\draw [arrow] (ecu) -- (obd);
\draw [arrow] (obd) -- (profiling);
\draw [arrow] (profiling) -- (score);
\draw [arrow] (profiling) -- (ml);

\end{tikzpicture}
} % Fine del \scalebox
\caption{Diagramma di flusso del sistema di profilazione conducente: la board è in grado di attribuire un voto al conducente; è inoltre possibile affiancare a questa capacità delle tecniche di machine learning adoperate per classificare lo stile di guida dei diversi clienti della flotta}
\label{fig:ProfilazioneML}
\end{figure}

\cleardoublepage
\phantomsection
\addcontentsline{toc}{chapter}{Elenco delle figure} %\todo{AT: forse vanno in fondo i due elenchi}
\listoffigures

\cleardoublepage
\phantomsection
\addcontentsline{toc}{chapter}{Elenco delle tabelle}
\listoftables

\chapter*{Ringraziamenti}
\addcontentsline{toc}{chapter}{Ringraziamenti}  % Aggiunge i ringraziamenti all'indice
Giunto alla conclusione di questo cammino, mi rendo conto che il percorso universitario non è stato solo una crescita personale e accademica, ma anche un percorso arricchito dalla presenza di persone che hanno contribuito a rendere questa esperienza unica.
Vorrei ringraziare profondamente la mia famiglia, per il loro supporto, l'incoraggiamento costante e la fiducia che hanno sempre riposto in me; i vostri sacrifici e la vostra pazienza mi hanno dato la forza di superare ogni difficoltà e raggiungere questo importante traguardo.
Un ringraziamento in particolare va a mio fratello Andrea, che è stato un esempio di determinazione e impegno: il suo sostegno e la sua capacità di farmi vedere il lato positivo in qualsiasi circostanza, hanno fatto la differenza.
Un pensiero affettuoso va ai miei amici e colleghi, che hanno condiviso con me gioie e sfide durante questi anni. Grazie di avermi ricordato l'importanza di ridere, di prendersi delle pause e di vivere ogni momento con entusiasmo.
Dei ringraziamenti speciali vanno al mio relatore, il Professor Andrea Trentini e al mio correlatore Alexjan Carraturo, che con pazienza, disponibilità e grande competenza mi hanno guidato in questo percorso. La loro prontezza nel rispondere a ogni mio dubbio e chiarire ogni mia domanda è stata fondamentale per la realizzazione di questa tesi e soprattutto per la mia crescita accademica.
Infine, il mio ringraziamento più sentito va alla mia ragazza Chiara, il cui amore, la cui pazienza e la cui comprensione hanno reso possibile tutto questo. Sei stata al mio fianco in ogni passo, offrendo sempre il tuo sostegno e la tua presenza, e per questo ti sarò sempre grato.

\printbibliography[title={Bibliografia}]

\end{document}

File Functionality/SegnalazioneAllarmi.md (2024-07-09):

# Segnalazione allarmi

## Introduzione
Il meccanismo di segnalazione allarmi prevede tre diversi tipi di dinamiche:
- Assistenza incidente
- Assistenza cliente
- Avvertimento di alcuni sistemi non funzionanti / segnalazione di alcune situazioni anomale 

1) L'assistenza incidente tratta la dinamica relativa ad un incidente stradale, inviando le coordinate GPS ed un insieme di informazioni utili ad una stazione remota dell'autonoleggio, sarà proprio lei ad avvisare i soccorsi che poi andranno a recarsi nel preciso punto di impatto.
2) L'assistenza cliente include due semplici funzionalità: la prima di Sos dove il cliente si mette in contatto con un operatore dell'autonoleggio per qualsiasi necessità/bisogno, la seconda prevede la chiamata ad un carro attrezzi con il relativo invio di coordinate GPS.
3) Per concludere, l'ultima dinamica è quella più interessante che consiste nel rilevamento di alcuni malfunzionamenti del veicolo e di alcuni comportamenti non corretti da parte del cliente a bordo dell'autovettura. Di seguito approfondiremo quest'ultima dinamica in modo più dettagliato

## Piccola overview del sistema proposto
Per gestire le situazioni relative all'ultima dinamica, il sistema (black box) viene dotato di 3 LED (verdo, giallo, rosso) per indicare diversi tipi di situazioni e per suggerire al cliente il corretto comportamento da intraprendere nel caso dell'accensione di una spia (led) indicante una situazione di avvertimento/pericolo:
1. Led verde: il veicolo funziona correttamente e il comportamento del conducente è corretto.
2. Led giallo: indica un AVVERTIMENTO, se vengono rilevati problemi di poca rilevanza o eseguite azioni non lecite viene azionato il led; dopo un breve periodo ad esempio 1/2 giorni nel quale continua a persistere il problema o l'azione, viene avvertita la centrale operativa. Un esempio di azione non lecita è il divieto di fumo all'interno del veicolo, se viene rilevata una sola volta la presenza di fumo all'interno dell'abitacolo non viene avvisata la centrale; per cui il motto di questa spia è: se un problema di poca rilevanza o un'azione persistono, avverto la centrale operativa.
3. Led rosso: indica una situazione di PERICOLO, in questo caso la centrale operativa viene avvertita immediatamente.

Di seguito verranno proposte le dinamiche delle situazioni per le quali viene attivata una spia gialla piuttosto che una rossa:

__Situazioni azionamento led giallo:__
- Divieto di fumo all'interno dell'abitacolo per il mantenimento di un ambiente pulito e privo di odori sgradevoli per i successivi clienti. La presenza di fumo può essere rilevata da un sensore.
- Rilevamento guida su terreni non adatti: fuoristrada o percorsi non asfaltati sono vietati al conducente per evitare danni al veicolo. La presenza di terreni disconnessi può essere rilevata con l'accelerometro utilizzando l'asse verticale (z).
- Rilevamento guida su aree geografiche non percorribili: non posso recarmi ovunque con il veicolo della compagnia. La segnalazione di aree non percorribili può essere rilevata grazie al GPS.
- Rilevamento attività di trasporto/rimorchio: non posso trainare nulla con il veicolo a noleggio. E' possibile rilevare l'attività con alcuni parametri provenienti dalla rete CAN-BUS ad esempio carico motore e velocità.

__Situazioni azionamento led rosso:__
- Distanza di frenata anomala: analizzando i dati di accelerazione e velocità del veicolo è possibile rilevare situazioni in cui la distanza di frenata è SIGNIFICATIVAMENTE più lunga, ciò può indicare un problema al sistema frenante o all'aderenza dei pneumatici. Si può rilevare tale situazione utilizzando i dati della rete CAN-BUS.
- Consumo anomalo di carburante: monitorando il consumo di carburante del veicolo e confrontandolo con i modelli di consumo attesi per determinate condizioni di guida (città, autostrada...) è possibile rilevare anomalie che potrebbero indicare perdite di carburante o problemi al motore, anche questa situazione può essere rilevata considerando i dati della rete CAN-BUS.
- Monitoraggio della qualità dell'aria nell'abitacolo: utilizzando sensori di qualità dell'aria il veicolo può rilevare la presenza di gas nocivi. Attività che può essere rilevata con lo stesso sensore utilizzato per rilevare i fumi.
- Rilevamento presenza di alcool: non è consentito al conducente mettersi alla guida in stato di ebrezza. Questa attività può essere monitorata attraverso un sensore che rileva la presenza di etanolo/alcohol nell'ambiente. Punto debole: non è possibile trasportare sul sedile del passeggero qualcuno che abbia bevuto. Ho pensato che se si potesse leggere in qualche modo il valore di pressione esercitata sul sedile del passeggero (True/False) si potrebbe ovviare al problema sopra citato chiedendo al guidatore se è coscente di trasportare un passeggero in stato di ebrezza, utilizzando quindi una modalità di conferma.
__Di seguito alcune situazioni meno interessanti, ma comunque rilevanti per la sicurezza:__
- Temperatura anomala del motore: il motore non lavora nel suo range di temperatura e potrebbe guastarsi. Sensoristica: CAN-BUS.
- Temperatura refrigerante: la temperatura del liquido di raffreddamento del motore, solitamente espressa in gradi Celsius può essere critica. Sensoristica: CAN-BUS.
- Coppia motore "torque": mantenere la coppia del motore entro limiti ottimali è essenziale per garantire prestazioni efficienti e sicure del veicolo, prevenendo l'usura prematura del motore e della trasmissione. Se la coppia è troppo bassa, si rischia una scarsa accelerazione; se troppo alta, si può verificare un eccessivo consumo di carburante e possibili danni meccanici.
Sensoristica: CAN-BUS.

## Configurazione
### - Assistenza incidente
Sostanzialmente il meccanismo si divide in due fasi: la fase di RILEVAMENTO e quella di NOTIFICA.

```mermaid
graph TD
  a[Start] --> b(Read the status of sensor)
  b --> c(Read the data from GPS)
  c --> d{Sensor is triggered?}
  d --> |No| b
  d --> |Yes| e(Send SMS using GSM)
  e --> f(END)
```

__Accelerometro__: nella fase di rilevamento l'accelerometro continua ad estrarre informazioni relative alla forza G (forza di accelerazione) sperimentata dagli occupanti.
__GPS__: nella fase di notifica è utile per inviare le coordinate GPS alla stazione remota.
__VELOCITA' VEICOLO__: nella fase di notifica viene mandata alla stazione remota e può essere usata per future ricostruzioni/analisi dell'incidente.

Per il rilevamento di una situazione di incidente posso usare un accelerometro, in un evento del genere la black box subirà la stessa accelerazione degli occupanti del veicolo. La forza G che si ricava dall'accelerazione deve essere ragionevolmente alta per un incidente, per questo non vengono considerati incidenti se tutte le accelerazioni sono inferiori a 4/5G. Infatti sulle auto gli airbag non vengono altro che azionati dal superamento di una certa soglia di accelerazione.
Come secondo filtro viene utilizzato un sistema di conferma per evitare i falsi positivi, all'utente vengono concessi 30 secondi per annullare il rilevamento della situazione di incidente, terminati i 30sec la chiamata partirà in automatico, in caso di annullamento si ritornerà ad una situazione di partenza

```mermaid
graph TD
  a[Inizio] --> b(Read data)
  b --> c{G force triggered}
  c --> |No| b
  c --> |Yes| d(Rilevamento incidente)
  d --> f{user abort}
  f --> |Yes| b
  f --> |No| g(Send accident SMS)
  g --> h(END)
```

```sh
Incidente = I
Accident_threshold  = 1
I = 1 se ((Accelerazione/4G) >= (Accident_threshold)) && !userAbort
I = 0 altrimenti
```

A seguito dell'incidente le informazioni che possono essere trasportate sono: **G-force** per capire quanto effettivamente è stato forte l'impatto, la **velocità del veicolo** per capire a quanto stava andando, le coordinate GPS **latitudine** e **longitudine** per capire dove è avvenuto l'incidente e in che **momento** è avvenuto (time).

Punto di debolezza: in caso di incidente estremo se la black box viene distrutta non è possibile contattare i soccorsi.
### - Assistenza cliente
Utilizzo di un bottone per gestire sia Sos che la chiamata al carro attrezzi, premendo il bottone per una durata di 5 sec mi metto in contatto con la centrale operativa, premendolo invece per 10 sec mi metto in contatto con il carro attrezzi (+ invio coordinate GPS).
### - Avvertimento di alcuni sistemi non funzionanti / segnalazione di alcune situazioni anomale
Per ogni casistica utilizzo opportuni sensori per catturare i possibili problemi del veicolo o comportamenti scorretti del cliente:
comportamento/problema : sensore di rilevamento
- Fumo : rilevatore di fumi
- Guida in fuoristrada : accelerometro
- Guida fuori dal range permesso : GPS
- Rimorchio/traino : dati CAN-BUS
- Distanza di frenata anomala : dati CAN-BUS
- Consumo anomalo di carburante : dati CAN-BUS
- Monitoraggio qualità aria abitacolo : rilevatore gas
- Rilevamento presenza di alcohol nell'abitacolo : rilevatore etanolo/alcohol
- Temperatura olio motore : dati CAN-BUS
- Temperatura liquido refrigerante : dati CAN-BUS
- Coppia motore : dati CAN-BUS

## Feedback del corretto funzionamento
Per verificare il corretto funzionamento delle casistiche che coinvolgono i dati provvenienti dalla rete CAN-BUS è necessario modificarne i valori degli attributi coinvolti, simulando così tutti i possibili scenari e verificare che il sistema reagisca in modo appropriato. Per quanto riguarga il coinvolgimento dei vari sensori è opportuno simulare tutte le varie situazioni possibili e verificare anche in questo caso che il sistema reagisca coerentemente con il funzionamento atteso.

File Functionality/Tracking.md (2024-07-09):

# Real-time vehicle tracking

## Introduzione
Questa funzionalità del sistema viene usata per monitorare e localizzare i veicoli della flotta ovunque si trovino. Il sistema di tracking
è in grado di generare la posizione esatta del veicolo usando due precisi parametri, latitudine e longitudine;
i dati di geolocalizzazione possono poi essere trasferiti e memorizzati all'interno di un computer per analisi future,
ad esempio visualizzare i percorsi abituali del cliente o il percorso effettuato in un preciso giorno. Il sistema di tracking può essere molto utile anche in caso di furto del veicolo.

## Piccola overview del sistema proposto
L'antenna GPS e il ricevitore GPS ricevono informazioni dal satellite nel formato NMEA (National Marine Electronics Association),
queste vengono processate dalla board di interesse e trasmesse al server via SMS (Short message service) o GPRS (General Package radio service). Una tra queste due comunicazioni provvederà ad aprire una connessione HTTP con il server di tracking usando la rete GSM (modulo provvisto di antenna) con i relativi comandi Hayes command (AT Command), il server una volta ricevuti i dati li memorizza in un qualunque database per analisi future.

Schema generale:
Antenna GPS + modulo GPS (ricezione coordinate) -> microcontrollore (board utilizzata per processare i dati)
->  Antenna GSM + modulo GSM (comunicazione informazioni ad un server remoto qualsiasi).

## Configurazione
Possibile componentistica hardware utilizzabile: modulo GPS NEO 6M, board prescelta e modulo SIM800A.
La SIM800A ha bisogno di 2A, vieni quindi collegata una alimentazione esterna di 12V.
Il GPS lo si può connettere a dei semplici pin digitali di input/output della board.
SIM800A è connesso anche lui a dei pin digitali di input/output.

```mermaid
graph LR
  a(GPS __ricezione dati__)
  b(microcontrollore __i dati vengono processati__)
  c(GSM __trasferisce i dati via GPRS o SMS__)
  
  a-->b
  b-->c
```

## Imprecisione
In molti casi il GPS potrebbe darci una risposta errata o non sufficientemente precisa, dovuta a molti fattori esterni, ad esempio:
condizioni del tempo atmosferico e all'ambiente che circonda il veicolo.

## Feedback del corretto funzionamento
Provare a percorrere una tragitto in auto e considerando piccoli slot temporali provare a ricostruirlo, visualizzandolo su una mappa.

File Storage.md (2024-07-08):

# Struttura interna del db per la gestione dei dati raccolti 
_Numeri alti indicano priorità alta_

### Tabella principale di memorizzazione dati (sensori/can bus) T1:
|nome_sensore|valore|tipo_dato|unita_misura|timestamp|synchronised|priority
|:---:|:---:|:---:|:---:|:---:| :---:|:---:
|TEXT|TEXT|TEXT|TEXT|INTEGER (numero di secondi trascorsi dall'epoc)|INTEGER (boolean)|INTEGER
|"Liquido raffreddamento"|"98"|"Integer"|"°C"|1715786497|0|3
|"Voltaggio batteria"|"12.3"|"Float"|"Volt (V)"|1715269497|1|8

### Tabella tempo di campionamento T2:
|nome_sensore|tempo_storage (ogni quanto memorizzare il valore)|variabile (indica se il tempo di storage può cambiare)|fattore_incr_decr (di quanto aumentare o diminuire il tempo di storage)|soglia (delimita se i dati campionati sono omogenei "<" o eterogenei ">")|tMinStorage (tempo minimo di storage)|tMaxStorage (tempo massimo di storage)
|:---:|:---:|:---:|:---:|:---:|:---:|:---:|
|TEXT|INTEGER (espressa in secondi) |INTEGER (boolean)|INTEGER|INTEGER|INTEGER|INTEGER|
|"Olio motore temp"|45|1|15|0.25|45|600
|"Coordinate GPS"|30|0|NULL|NULL|NULL|NULL

### Tabella profilazione guida T3:
|data (YYYY-MM-GG HH:MM:SS, data in cui il voto è stato registrato)|voto|lastStorage (momento in cui è stato memorizzato il voto "in secondi") |synchronised
|:---:|:---:|:---:|:---:|
|TEXT|TEXT|INTEGER|INTEGER (boolean)|
|"2024-03-10 12:00:00"|0.99|1715786497|1|
|"2024-07-07 17:56:20"|0.53|1815786497|0|

### Tabella allarmi critici T4:
|problema|data (YYYY-MM-GG HH:MM:SS)|synchronised|
|:---:|:---:|:---:|
|TEXT|TEXT|INTEGER (boolean)|
|"Alcool"|"2024-07-07 17:56:20"|1715786497|1|
|"Gas nell'abitacolo"|"2024-07-11 17:56:20"|1815786497|0|

### Tabella allarmi meno critici T5:
|problema|rilevamenti|soglia (il numero max di rilevamenti)|daMandare|synchronised
|:---:|:---:|:---:|:---:|:---:|
|TEXT|INTEGER|INTEGER|INTEGER (boolean)|INTEGER (boolean)|
|"Fumo"|3|3|1|0|
|"Fuori range GPS"|0|5|0|0|

## Meccanismo cambio tempo di storage
```mermaid
graph TD
  A[Sensor data] -->|Receiving data| B(Calculation of average and standard deviation)
  B -->|After n readings, changeTimeStorage function| C{Is std low?}
  C -->|YES| D[Increase time storage in DB by: fattore_incr_decr]
  C -->|NO| E[Decrease time storage in DB by: fattore_incr_decr]
```
Logica: se dopo una serie di letture (n ad esempio) i dati hanno una bassa deviazione standard, ovvero sono molto simili tra di loro, memorizzo i dati del veicolo con una frequenza minore, aumentando il tempo di storage di un certo fattore (presente nella seconda tabella di questo file); se la deviazione standard è alta, significa che i dati sono abbastanza differenti tra di loro e li monitoro con una frequenza maggiore. Naturalmente vengono posti dei lower e upper bound per il tempo di memorizzazione entro i quali il tempo stesso può variare

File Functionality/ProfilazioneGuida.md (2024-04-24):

# Profilazione guida
## Introduzione
Nel quadro del nostro progetto di analisi della profilazione guida, sfruttiamo tecnologie di acquisizione dati per ottenere una comprensione dettagliata del comportamento del guidatore. A tale scopo, facciamo uso di due principali fonti di informazioni: i dati provenienti dal sistema di diagnostica a bordo (OBD-II) e quelli registrati da un accelerometro. Questi dispositivi forniscono una vasta gamma di dati in tempo reale, quali ad esempio velocità, accelerazione, decelerazione (frenata) e angoli di sterzata, consentendo di valutare numerosi aspetti relativi alla guida. Attraverso l'analisi approfondita di tali dati, siamo in grado di creare profili individuali dei guidatori e identificare modelli di comportamento distintivi che influenzano la sicurezza, l'efficienza e l'affidabilità del veicolo. Nel corso di questa relazione, esploreremo come l'integrazione di queste tecnologie ci permetta di ottenere informazioni preziose per migliorare l'esperienza di guida e ottimizzare le operazioni di gestione della flotta.

## Piccola overview del sistema proposto
I principali parametri che vengono catturati per l'analisi del guidatore sono: **rpm** ovvero i giri motore al minuto, la **velocità dell'auto**, il **carico del motore** e la **valvola a farfalla** provenienti dalla rete CAN-BUS presente all'interno del veicolo, **accelerazione**, **decelerazione** (frenata) e **sterzate** provengono invece dall'accelerometro.
Una volta che la black box riceve i valori dei parametri, essa è in grado di analizzarli e riconoscere situazioni riconducibili ad una guida impropria raccogliendo il numero in cui si verificano tali situazioni all'interno di una struttura dati, dopo un periodo di 24h i dati vengono elaborati per calcolare un punteggio di guida compreso tra 0 e 1. Questo punteggio potrebbe essere utilizzato dalla compagnia per varie finalità, come ad esempio fornire incentivi ai guidatori che adottano comportamenti più sicuri.
Ecco le principali fasi del sistema proposto:

```mermaid
graph LR
  a(Data sensing)
  b(Data acquisition)
  c(Data processing)
  d(Data storage)

  a-->b
  b-->c
  c-->d
```

1. Data sensing: i dati provenienti dal motore della macchina ad esempio rpm, velocità, accelerazione... vengono percepiti dall'unità di controllo ECU
2. Data acquisition: i dati acquisiti dalla ECU vengono trasferiti via Bluetooth alla board prescelta utilizzando un adattatore OBD-II
3. Data processing: i dati trasferiti attraverso l'OBD-II sono processati dalla board di interesse
4. Data storage: vengono memorizzati in una struttura dati i valori di alcuni parametri che vengono ritenuti significativi per la valutazione finale del guidatore

ECU è l'unità centrale di controllo del veicolo dove sono collegati tutti i vari sensori presenti all'interno del veicolo: motore dell'auto, aria condizionata, livello carburante, corpo dell'auto... . L'adapter OBD-II trasmette i dati dalla ECU alla board di interesse via Bluetooth. La board processa i dati ed è in grado di generare uno score del guidatore.
Il punteggio [0,1] viene calcolato considerando:
-   Il numero di eccessi di velocità dati dalla differenza tra i limiti imposti dalla legge e quelli reali del veicolo
-   Le accelerazioni e decelerazioni brusche
-   Le sterzate sia a sinistra che a destra brusche
-   Il rapporto (relativo) di velocità del veicolo con i giri del motore che deve essere compreso tra i valori di 0.9-1.3 per una buona guida
-   Il rapporto (relativo) tra la valvola a farfalla e i giri del motore che deve essere compreso tra i valori di 0.9-1.3 per una buona guida
-   Il carico del motore che deve essere compreso tra il 20% e il 50% per una buona guida

## Configurazione
Per quanto riguarda il secondo e il terzo punto è possibile utilizzare un accelerometro a 3 assi utile per monitorare le accelerazioni/decelerazioni e le sterzate improvvise:

| Asse | Direzione | Azione/Evento |
| --- | --- | --- |
| x | sinistra/destra | sterzata
| y | anteriore/posteriore | accelerazione/decelerazione (frenata)
| z | su/giù | strada dissestata

Accelerometro

Per quanto riguarda i punti 4 e 5 è possibile calcolarli per via analitica conoscendo i dati provenienti dall'OBD-II, mentre per l'ultimo punto (carico motore espresso in %) non si ha bisogno di alcuna manipolazione dei dati in quanto essi provengono direttamente dalla rete CAN-BUS.

### Tabella valutativa
Per valutare il comportamento del guidatore di seguito vengono mostrati i vari livelli di punteggio del guidatore che posso essere ottenuto dopo un periodo di 24h di monitoraggio guida

| Driver score | Driving behaviour |
|---|---|
| < 0.10 | Safe |
| 0.1 - 0.19 | Modest |
| 0.19 - 0.38  | Moderate Risk |
| 0.38 - 0.56  | Risk |
| 0.56 - 0.75  | Reckless |
| > 0.75 | Critical |

_*Il punteggio del guidatore è inteso come la probabilità di rischio di procurare un incidente a seguito del viaggio osservato, pertanto sarà compreso tra 0 e 1*_.

Per concludere il nostro studio possiamo affiancare alla capacità della board di valutazione del guidatore, tecniche di Machine Learning relative sia all'apprendimento supervisionato che non supervisionato, consentendoci di esaminare più approfonditamente la natura della nostra flotta.
In questo contesto, ci concentreremo su due principali tecniche di Machine Learning: la _*classificazione*_ e il _*clustering*_. La classificazione ci permette di assegnare ai guidatori delle etichette, come ad esempio 'prudente' o 'negligente', in base ai loro comportamenti al volante, mentre il clustering ci consente di raggruppare i guidatori in base a similitudini nel comportamento di guida. Esploreremo queste tecniche nel dettaglio, evidenziando le loro applicazioni specifiche e i benefici che possono apportare all'analisi dei guidatori e alla gestione dell'autonoleggio.
## Machine Learning nell'analisi dei guidatori: applicazioni nel nostro contesto
Una volta processati i dati relativi all'analisi di profilazione del guidatore, essi possono essere inviati ad un server remoto. Dopodichè è possibile usare varie tecniche di machine learning di apprendiamento supervisionato ad esempio la **classificazione** o di apprendimento non supervisionato ad esempio il **clustering**, per assegnare ai clienti dell'autonoleggio una certa etichetta di classificazione (prudenti o negligenti) o raggrupparli in cluster e osservare il comportamento della flotta.
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

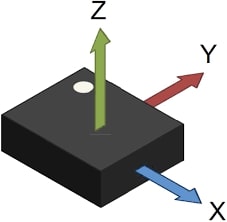
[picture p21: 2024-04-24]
img/Accelerometro.jpg

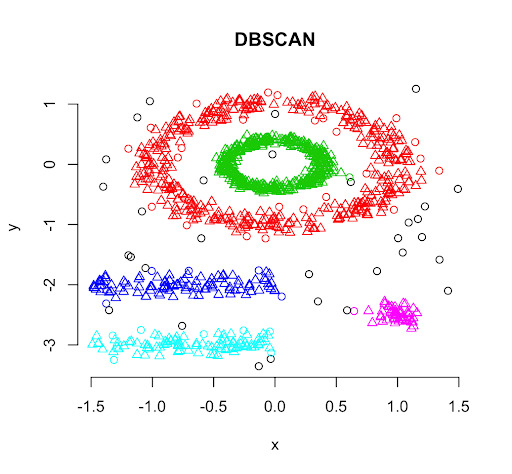
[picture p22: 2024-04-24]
img/ClusterizzazioneD.jpg

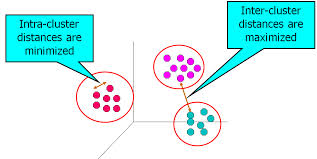
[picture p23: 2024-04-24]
img/ClusterirrazioneP.jpg

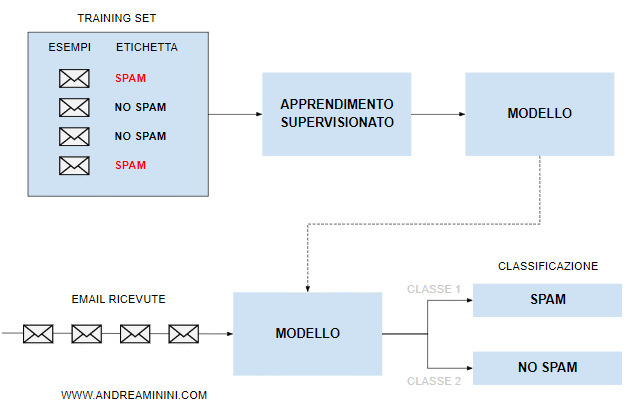
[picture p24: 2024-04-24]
img/Classificazione.jpg

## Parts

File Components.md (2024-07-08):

_Inventario dei sensori utili e stima delle componenti che mi serviranno_

## Componenti e sensori necessari:
- Led utile per "segnalazione allarmi":
3 led (verde, giallo, rosso)
3 resistori 
3 collegamenti grd
3 pin digitali
- Sensore di rilevamento gas e fumo utile per "segnalazione allarmi": 
1 modulo MQ-2
1 collegamento a grd
1 collegamento a Vcc (5V)
1 pin digitale
1 pin analogico
- Accelerometro utile per "segnalazione allarmi/profilazione guida":
1 scheda GY-521 MPU-6050 
1 collegamento a grd
1 collegamento a Vcc (5V)
2 pin analogici (SDA/SCL)
- GPS utile per "tracking/segnalazione allarmi":
1 modulo NEO-6M GPS
1 collegamento a grd
1 collegamento a Vcc (5V)
2 pin digitali (TX/RX)
- Sensore di rilevamento alcool utile per "segnalazione allarmi":
1 modulo MQ-3
1 collegamento a grd
1 collegamento a Vcc (5V)
1 pin analogico
1 pin digitale
- Display utile per "segnalazione allarmi":
1 Display LCD 16X2
1 collegamento a grd
1 collegamento a Vcc (5V)
2 pin analogici (SDA/SCL)
- Pulsante utile per "segnalazione allarmi":
1 pulsante
1 resistore
1 collegamento a grd
1 collegamento a Vcc (5V)
1 pin digitale
- Modulo RTC utile per monitoraggio orario in assenza di connessione
1 collegamento a grd
1 collegamento a Vcc (5V)
2 pin analogici (SDA/SCL)

- Totale collegamenti a grd: 10
- Totale collegamenti a Vcc: 7
- Totale pin digitali sfruttati: 8
- Totale pin analogici sfruttati: 8
- Breadboard da 830 pin: 2
- Stima jumper totali: 40/45
- Stima numero totale di sensori: 8
#### Board proposta: ESP32
##### caratteristiche:
bluetooth 4.2 e ble, modulo wi-fi, dual core, ADC 12 bit, funziona a 3.3V

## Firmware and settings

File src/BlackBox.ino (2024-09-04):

#include <TaskScheduler.h>
#include <LittleFS.h>
#include <Wire.h>
#include <TinyGPSPlus.h>
#include <SoftwareSerial.h>
#include <HardwareSerial.h>
#include <LiquidCrystal_I2C.h>
#include <Adafruit_MPU6050.h>

#include "BluetoothSerial.h"
#include "ELMduino.h"

#include "Secrets.h"
#include "Config.h"

#include "LocalTime.h"
#include "Storage.h"
#include "FileSystem.h"
#include "Synch.h"
#include "Garbage.h"
#include "Dato.h"

LiquidCrystal_I2C lcd(0x27, 16, 2);
Adafruit_MPU6050 mpu;
Scheduler scheduler;
sqlite3* db;
RTC_DS3231 rtc;
TinyGPSPlus gps;
HardwareSerial ss = Serial2;

BluetoothSerial SerialBT;
ELM327 myELM327;
// Indirizzo MAC del dispositivo Bluetooth a cui ci si desidera connettere
uint8_t remoteAddress[] = { 0x10, 0x21, 0x3E, 0x4C, 0x6F, 0x3A };

// Dati relativi al monitoraggio
Dato accelerometro_Sensor("Accelerometria", MAX_READINGS_ACCELEROMETRIA);
Dato alcool_Sensor("Alcool", MAX_READINGS_ALCOOL);
Dato airQuality_Sensor("Qualità aria", MAX_READINGS_AIRQUALITY);
Dato gps_Sensor("Coordinate GPS", MAX_READINGS_GPS);
Dato coolantTemp_Sensor("Liquido raffreddamento", MAX_READINGS_LIQ_RAFFR);
Dato oilTemp_Sensor("Olio motore temp", MAX_READINGS_OIL);
Dato torque_Sensor("Coppia motore", MAX_READINGS_TORQUE);
Dato batteryV_Sensor("Voltaggio batteria", MAX_READINGS_BATTERIA_V);
Dato fuelLevel_Sensor("Livello carburante", MAX_READINGS_CARBURANTE_LEVEL);

typedef enum {
  ENG_RPM,          // Giri al minuto del motore
  KPH,              // Velocità del veicolo in chilometri orari
  THROTTLE,         // Posizione della valvola a farfalla
  LOAD,             // Carico del motore in percentuale
  COOLANT_TEMP,     // Temperatura del liquido di raffreddamento
  TORQUE,           // Coppia del motore
  BATTERY_VOLTAGE,  // Voltaggio della batteria
  OIL_TEMP,         // Temperatura dell'olio motore
  FUEL_LEVEL        // Livello del carburante in percentuale
} obd_pid_states;
obd_pid_states obd_state = ENG_RPM;

// ### Dati OBD ###
float rpm = 0;
float kph = 0;
float throttle = 0;
float load = 0;
float coolant_temp = 0;
float torque = 0;
float battery_voltage = 0;
float oil_temp = 0;
float fuel_level = 0;

// ### Profilazione ###
int campionamento_Profilazione = 0;
int nRilevamentiAccDecBrusche = 0;
int nRilevamentiSterzateBrusche = 0;
int nRilevamentiFatt1 = 0;
int nRilevamentiFatt2 = 0;
int nRilevamentiCaricoMotoreOutOfRange = 0;

// ### Allarmi critici ###
int campionamento_AllarmiRed = 0;
int nRilevamentiAlcool = 0;
int nRilevamentiGas = 0;
int nRilevamentiTempEngineCritic = 0;
int nRilevamentiTempOilCritic = 0;
int nRilevamentiCoppiaEngineCritic = 0;

// ### Allarmi meno critici ###
int campionamento_AllarmiYellow = 0;
int nRilevamentiFumo = 0;
int nRilevamentiFuoriStrada = 0;
int nRilevamentiFuoriNazione = 0;
int nRilevamentiRimorchi = 0;
bool Superata_Soglia_Fumo = 0;
bool Superata_Soglia_FuoriStrada = 0;
bool Superata_Soglia_RangeGPS = 0;
bool Superata_Soglia_Rimorchi = 0;

// ### Assistenza
struct Button {
	const uint8_t PIN;
	bool pressed;
};
Button button = {BUTTON_PIN, false};

void accelerometriaCallback();
void airMonitoringCallback();
void gspTrackerCallback();
void obdComunicationCallback();
void carParametersCallback();

void profilazioneCallback();
void segnalazioneAllarmiRedCallback();
void segnalazioneAllarmiYellowCallback();

void synchDataCallback();
void cleanDataRoutineCallback();
void cleanDataMemoryFullCallback();
void cleanAllarmCallback();
#ifdef DEBUG
void loggingCallback();
#endif
void GPSTrackingCallback();
void accidentAndAssistanceCallback();

Task accelerometriaTask(ACCELEROMETRIA_READ_INTERVAL, TASK_FOREVER, &accelerometriaCallback);
Task airMonitoringTask(AIR_READ_INTERVAL, TASK_FOREVER, &airMonitoringCallback);
Task gpsTrackerTask(GPS_READ_INTERVAL, TASK_FOREVER, &gspTrackerCallback);
Task obdTask(OBD_READ_INTERVAL, TASK_FOREVER, &obdComunicationCallback);
Task carParametersTask(CAR_OBD_STORAGE_INTERVAL, TASK_FOREVER, &carParametersCallback);

Task profilazioneTask(PROFILAZIONE_INTERVAL, TASK_FOREVER, &profilazioneCallback);
Task segnalazioneAllarmiRedTask(ALLARMI_INTERVAL, TASK_FOREVER, &segnalazioneAllarmiRedCallback);
Task segnalazioneAllarmiYellowTask(ALLARMI_INTERVAL, TASK_FOREVER, &segnalazioneAllarmiYellowCallback);

Task synchDataTask(SYNCHRONIZATION_DATA, TASK_FOREVER, &synchDataCallback);
Task cleanDataRoutineTask(CLEANING_ROUTINE, TASK_FOREVER, &cleanDataRoutineCallback);
Task cleanDataMemoryFullTask(CLEANING_MEMORY_FULL, TASK_FOREVER, &cleanDataMemoryFullCallback);
Task cleanAllarmTask(WEEK, TASK_FOREVER, &cleanAllarmCallback);

#ifdef DEBUG
Task loggingTask(CENTRALINA_LOG, TASK_FOREVER, &loggingCallback);
#endif

Task GPSTrackingTask(GPS_TRACKING_SECURITY, TASK_FOREVER, &GPSTrackingCallback);
Task accidentAndAssistanceTask(ACCIDENT_AND_ASSISTANCE, TASK_FOREVER, &accidentAndAssistanceCallback);

void IRAM_ATTR isr() {
	button.pressed = true;
}

void setup() {

  Serial.begin(115200);

  Wire.begin();
  if (!rtc.begin()) {
    #ifdef DEBUG
    Serial.println("Couldn't find RTC");
    #endif
  }

  ss.begin(GPSBAUD);

  lcd.init();
  lcd.backlight();
  lcd.setCursor(0, 0);
  lcd.print("Benvenuto a");
  lcd.setCursor(0, 1);
  lcd.print("bordo");

  pinMode(LED_ROSSO, OUTPUT);
  pinMode(LED_GIALLO, OUTPUT);
  pinMode(LED_VERDE, OUTPUT);
  digitalWrite(LED_ROSSO, HIGH);
  digitalWrite(LED_GIALLO, HIGH);
  digitalWrite(LED_VERDE, LOW);

  pinMode(button.PIN, INPUT_PULLUP);
	attachInterrupt(button.PIN, isr, RISING);

  if (!mpu.begin(0x69)) {
    #ifdef DEBUG
    Serial.println("MPU6050 non trovato!");
    #endif
  }
  #ifdef DEBUG
  Serial.println("MPU6050 trovato e inizializzato correttamente.");
  #endif

  pinMode(ALCOOL_PIN, INPUT);
  pinMode(AIR_QUALITY_PIN, INPUT);

  /* DA USARE PER LA VERSIONE UFFICIALE
  LittleFS.begin();
  if (!LittleFS.exists(DB_FILE)) {
    configurationProcess();
  } else {
    Serial.println("Database already exist");
  } */

  // La prima accensione va fatta in presenza di una connessione internet in modo tale da poter sincronizzare tutte le informazioni necessare per un corretto funzionamento futuro della Black Box
  // Da integrare meglio con le righe sopra di codice in caso di riavvio della blacl box in assenza di internet
  configurationProcess();

  obdConfig();

  scheduler.init();

  scheduler.addTask(accelerometriaTask);
  scheduler.addTask(airMonitoringTask);
  scheduler.addTask(gpsTrackerTask);
  scheduler.addTask(obdTask);
  scheduler.addTask(carParametersTask);

  scheduler.addTask(profilazioneTask);
  scheduler.addTask(segnalazioneAllarmiRedTask);
  scheduler.addTask(segnalazioneAllarmiYellowTask);

  scheduler.addTask(synchDataTask);
  scheduler.addTask(cleanDataRoutineTask);
  scheduler.addTask(cleanDataMemoryFullTask);
  scheduler.addTask(cleanAllarmTask);
  #ifdef DEBUG
  scheduler.addTask(loggingTask);
  #endif
  scheduler.addTask(GPSTrackingTask);
  scheduler.addTask(accidentAndAssistanceTask);

  accelerometriaTask.enable();
  airMonitoringTask.enable();
  gpsTrackerTask.enable();
  obdTask.enable();
  carParametersTask.enable();

  profilazioneTask.enable(); 
  // segnalazioneAllarmiRedTask.enable();
  segnalazioneAllarmiYellowTask.enable();

  synchDataTask.enable();
  // cleanDataRoutineTask.enable();
  // cleanDataMemoryFullTask.enable();
  // cleanAllarmTask.enable();
  #ifdef DEBUG
  loggingTask.enable();
  #endif
  // GPSTrackingTask.enable();
  // accidentAndAssistanceTask.enable();
}

void loop() {
  scheduler.execute();
}

// ACCELEROMETRIA TASK
void accelerometriaCallback() {
  sensors_event_t a, g, temp;
  mpu.getEvent(&a, &g, &temp);

  float x, y, z;
  x = a.acceleration.x;
  y = a.acceleration.y;
  z = a.acceleration.z;
  String res = String(x) + " / " + String(y) + " / " + String(z);

  long long int result = processSensorData(accelerometro_Sensor.lastStoredTS, accelerometro_Sensor.name, res.c_str(), "String", "m/s^2", 6);

  if (result != -1) {
    accelerometro_Sensor.lastStoredTS = result;
  }
}

// AIR MONITORING TASK
void airMonitoringCallback() {
  // Lettura sensore MQ-3
  int mq3AnalogValue = analogRead(ALCOOL_PIN);

  // Lettura sensore MQ-2
  int mq2AnalogValue = analogRead(AIR_QUALITY_PIN);

  /* DA INSERIRE NELLA VERSIONE UFFICIALE
  alcool_Sensor.addReading(mq3AnalogValue);
  airQuality_Sensor.addReading(mq2AnalogValue);
  // Fine delle mie x letture e cambio del tempo di storage
  if(alcool_Sensor.currentIndex == alcool_Sensor.maxReadings) {
    changeTimeStorage(alcool_Sensor);
  }
  if(airQuality_Sensor.currentIndex == airQuality_Sensor.maxReadings) {
    changeTimeStorage(airQuality_Sensor);
  } 
  */

  long long int resultAlcool = processSensorData(alcool_Sensor.lastStoredTS, alcool_Sensor.name, String(mq3AnalogValue).c_str(), "Integer", "Assente", 2);
  long long int resultAirQuality = processSensorData(airQuality_Sensor.lastStoredTS, airQuality_Sensor.name, String(mq2AnalogValue).c_str(), "Integer", "Assente", 2);

  if (resultAlcool != -1) {
    alcool_Sensor.lastStoredTS = resultAlcool;
  }
  if (resultAirQuality != -1) {
    airQuality_Sensor.lastStoredTS = resultAirQuality;
  }
}

// GPS TASK
void gspTrackerCallback() {
  double lat = -1;
  double lon = -1;

  while (ss.available() > 0) {
    gps.encode(ss.read());
  }
  if (gps.location.isValid()) {
    lat = gps.location.lat();
    lon = gps.location.lng();
  } else {
    #ifdef DEBUG
    Serial.println("INVALID LOCATION");
    #endif
  }

  String res = String(lat, 6) + " / " + String(lon, 6);

  long long int result = processSensorData(gps_Sensor.lastStoredTS, gps_Sensor.name, res.c_str(), "String", "°", 5);

  if (result != -1) {
    gps_Sensor.lastStoredTS = result;
  }
}

// PARAMETRI PROVENIENTI DAL VEICOLO TASK
void carParametersCallback() {
  String str1 = String(coolant_temp, 2);
  long long int res1 = processSensorData(coolantTemp_Sensor.lastStoredTS, coolantTemp_Sensor.name, str1.c_str(), "Integer", "°C", 1);
  String str2 = String(oil_temp, 2);
  long long int res2 = processSensorData(oilTemp_Sensor.lastStoredTS, oilTemp_Sensor.name, str2.c_str(), "Integer", "°C", 1);
  String str3 = String(torque, 2);
  long long int res3 = processSensorData(torque_Sensor.lastStoredTS, torque_Sensor.name, str3.c_str(), "Integer", "Newton metri (Nm)", 2);
  String str4 = String(battery_voltage, 2);
  long long int res4 = processSensorData(batteryV_Sensor.lastStoredTS, batteryV_Sensor.name, str4.c_str(), "Float", "Volt (V)", 3);
  String str5 = String(fuel_level, 2);
  long long int res5 = processSensorData(fuelLevel_Sensor.lastStoredTS, fuelLevel_Sensor.name, str5.c_str(), "Float", "%", 4);
  if (res1 != -1) {
    coolantTemp_Sensor.lastStoredTS = res1;
  }
  if (res2 != -1) {
    oilTemp_Sensor.lastStoredTS = res2;
  }
  if (res3 != -1) {
    torque_Sensor.lastStoredTS = res3;
  }
  if (res4 != -1) {
    batteryV_Sensor.lastStoredTS = res4;
  }
  if (res5 != -1) {
    fuelLevel_Sensor.lastStoredTS = res5;
  }
  /* DA INSERIRE NELLA VERSIONE UFFICIALE
  coolantTemp_Sensor.addReading(coolant_temp);
  oilTemp_Sensor.addReading(oil_temp);
  // Fine delle mie x letture e cambio del tempo di storage
  if(coolantTemp_Sensor.currentIndex == coolantTemp_Sensor.maxReadings) {
    changeTimeStorage(coolantTemp_Sensor);
  }
  if(oilTemp_Sensor.currentIndex == oilTemp_Sensor.maxReadings) {
    changeTimeStorage(oilTemp_Sensor);
  }
  */
}

// PROFILAZIONE TASK
void profilazioneCallback() {
  campionamento_Profilazione++;
  sensors_event_t a, g, temp;
  mpu.getEvent(&a, &g, &temp);

  float x = a.acceleration.x;
  float y = a.acceleration.y;

  /// Sterzate sinistra e destra brusche
  if ((x / FORZA_G) > (STERZATA_DX_BRUSCA) || (x / FORZA_G) < (STERZATA_SX_BRUSCA)) {
    nRilevamentiSterzateBrusche++;
  }
  // Accelerazioni / decelerazioni brusche
  if ((y / FORZA_G) > (ACCELERAZIONE_BRUSCA) || (y / FORZA_G) < (DECELERAZIONE_BRUSCA)) {
    nRilevamentiAccDecBrusche++;
  }
  // Fattore 1
  float fatt1 = ((kph / MAX_SPEED_CAR) / (rpm / MAX_RPM_CAR));
  if ((fatt1 < RANGE_INF) || (fatt1 > RANGE_SUP)) {
    nRilevamentiFatt1++;
  }
  // Fattore 2
  float fatt2 = ((throttle / 100) / (rpm / MAX_RPM_CAR));
  if ((fatt2 < RANGE_INF) || (fatt2 > RANGE_SUP)) {
    nRilevamentiFatt2++;
  }
  // Carico motore
  if ((load < LOAD_MIN) || (load > LOAD_MAX)) {
    nRilevamentiCaricoMotoreOutOfRange++;
  }
  if (campionamento_Profilazione == MAX_CAMPIONAMENTI_PROFILAZIONE) {  // (3 fa riferimento al numero di campionamenti che si desidera) && è trascorso un giorno dall'ultima storage (if presente all'interno della funzione updateCampionamentoProfilazione())
    updateCampionamentoProfilazione();
  }
}

// SEGNALAZIONE ALLARMI ROSSI TASK
void segnalazioneAllarmiRedCallback() {
  campionamento_AllarmiRed++;
  // Alcool
  int alcool = analogRead(ALCOOL_PIN);
  if (alcool > SOGLIA_ALCOOL) {
    nRilevamentiAlcool++;
  }
  // Gas abitacolo
  int gas = analogRead(AIR_QUALITY_PIN);
  if (gas < 0) {  // SOGLIA_QUAL_ARIA
    nRilevamentiGas++;
  }
  // Temperatura liquido di raffreddamento
  if (coolant_temp > MAX_COOLANT_TEMP) {
    nRilevamentiTempEngineCritic++;
  }
  // Temperatura olio motore
  if (oil_temp > MAX_OIL_TEMP) {
    nRilevamentiTempOilCritic++;
  }
  // Coppia motore
  if ((kph != 0) && (torque < MIN_TORQUE_THRESHOLD || torque > MAX_TORQUE_THRESHOLD)) {
    nRilevamentiCoppiaEngineCritic++;
  }
  // Consumo anomalo di carburante ?
  // Distanza di frenata anomala ?
  if (campionamento_AllarmiRed == MAX_CAMPIONAMENTI_ALLARMI_ROSSI) {  // bisogna mettere un valore molto alto dato che alcuni valori potrebbero essere errati per vari motivi + si vorrebbe essere il più precisi possibili
    updateRedAllarm();
  }
}

// SEGNALAZIONE ALLARMI GIALLI TASK
void segnalazioneAllarmiYellowCallback() {
  campionamento_AllarmiYellow++;
  // Fumo
  int airQuality = analogRead(AIR_QUALITY_PIN);
  if (airQuality > 0) {  // Andrà impostata una soglia per il fumo
    nRilevamentiFumo++;
  }
  /*
  // Fuori strada
  sensors_event_t a, g, temp;
  mpu.getEvent(&a, &g, &temp);
  float z = a.acceleration.z;
  if (z < (FORZA_G - TOLLERANZA_OFF_ROAD) || z > (FORZA_G + TOLLERANZA_OFF_ROAD)) {
    nRilevamentiFuoriStrada++;
  }
  // Range GPS
  double lat = -1;
  double lon = -1;
  if (ss.available() > 0) {
    gps.encode(ss.read());
  }
  if (gps.location.isValid()) {
    lat = gps.location.lat();
    lon = gps.location.lng();
    if (!isInsideNation(lat, lon)) {
      nRilevamentiFuoriNazione++;
    }
  }
  // Trasporto/rimorchio
  if (isTrailerAttached(rpm, kph, throttle, load, torque)) {
    nRilevamentiRimorchi++;
  }
  */
  if (campionamento_AllarmiYellow == MAX_CAMPIONAMENTI_ALLARMI_GIALLI) {  // bisogna mettere un valore molto alto dato che alcuni valori potrebbero essere errati per vari motivi + si vorrebbe essere il più precisi possibili
    updateYellowAllarm();
  }
}

// SINCRONIZZAZIONE TASK
void synchDataCallback() {
  obdTask.disable();
  if (WiFi.status() == WL_CONNECTED) {  // ed è passato abbastanza tempo >= 24h dall'ultima sincronizzazione
    #ifdef DEBUG
    Serial.println("Connessione WiFi attiva");
    #endif
    WiFi.begin(WIFI_SSID, WIFI_PASSWORD);
    while (WiFi.status() != WL_CONNECTED) {
      delay(500);
      #ifdef DEBUG
      Serial.println("Connecting to WiFi...");
      #endif
    }
    #ifdef DEBUG
    Serial.println("WiFi connected");
    Serial.println("---------------------------- Sincronizzazione ----------------------------");
    #endif
    syncMonitoraggioData(db);
    syncProfilazioneData(db);
    syncAllarmiRossiData(db);
    syncAllarmiGialliData(db);
  } else {
    #ifdef DEBUG
    Serial.println("Nessuna connessione WiFi");
    #endif
  }
  restoreBluetoothConnection();
  obdTask.enable();
}

// CLEAN ROUTINE TASK
void cleanDataRoutineCallback() {
  #ifdef DEBUG
  Serial.println("---------------------------- Pulisco routine ----------------------------");
  #endif
  garbageCollectorRoutine();
}

// CLEAN MEMORY FULL TASK
void cleanDataMemoryFullCallback() {
  /*
  if (raggiungo un 90 % di capienza adotto la mia politica) { -> non riesco a tener traccia di quanto il filesystem sia pieno !!!
    #ifdef DEBUG
    Serial.println("---------------------------- Pulisco memory ----------------------------");
    #endif
    garbageCollectorMemoryFull();
  } */
}

// CLEAN ALLARMI TASK
void cleanAllarmCallback() {
  Superata_Soglia_Fumo = false;
  Superata_Soglia_FuoriStrada = false;
  Superata_Soglia_RangeGPS = false;
  Superata_Soglia_Rimorchi = false;
  cleanAllarmiYellow(db);
  cleanAllarmiRed(db);
}

// SIMULAZIONE 
/*
void obdComunicationCallback() {
  rpm = random(750, MAX_RPM_CAR);
  kph = random(0, MAX_SPEED_CAR);
  throttle = random(10, 101);
  load = random(10, 101);
  coolant_temp = random(20, MAX_COOLANT_TEMP + 1);
  torque = random(MIN_TORQUE_THRESHOLD, MAX_TORQUE_THRESHOLD);
  battery_voltage = random(110, 130) / 10;
  oil_temp = random(25, MAX_OIL_TEMP + 1);
  fuel_level = random(0, 101);
} */
// COMUNICAZIONE OBD TASK
void obdComunicationCallback() {
    switch (obd_state)
    {
        case ENG_RPM:
        {
            float rpm_r = myELM327.rpm();
            if (myELM327.nb_rx_state == ELM_SUCCESS)
            {
                rpm = rpm_r;
                obd_state = KPH;
            }
            else if (myELM327.nb_rx_state != ELM_GETTING_MSG)
            {
                myELM327.printError();
                obd_state = KPH;
            }
            break;
        }

        case KPH:
        {
            float kph_r = myELM327.kph();
            if (myELM327.nb_rx_state == ELM_SUCCESS)
            {   
                kph = kph_r;
                obd_state = THROTTLE;
            }
            else if (myELM327.nb_rx_state != ELM_GETTING_MSG)
            {
                myELM327.printError();
                obd_state = THROTTLE;
            }
            break;
        }

        case THROTTLE:
        {
            float throttle_r = myELM327.throttle();
            if (myELM327.nb_rx_state == ELM_SUCCESS)
            { 
                throttle = throttle_r;
                obd_state = LOAD;
            }
            else if (myELM327.nb_rx_state != ELM_GETTING_MSG)
            {
                myELM327.printError();
                obd_state = LOAD;
            }
            break;
        }

        case LOAD:
        {
            float load_r = myELM327.engineLoad();
            if (myELM327.nb_rx_state == ELM_SUCCESS)
            {
                load = load_r;
                obd_state = COOLANT_TEMP;
            }
            else if (myELM327.nb_rx_state != ELM_GETTING_MSG)
            {
                myELM327.printError();
                obd_state = COOLANT_TEMP;
            }
            break;
        }

        case COOLANT_TEMP:
        {
            float coolant_temp_r = myELM327.engineCoolantTemp();
            if (myELM327.nb_rx_state == ELM_SUCCESS)
            {
                coolant_temp = coolant_temp_r;
                obd_state = TORQUE;
            }
            else if (myELM327.nb_rx_state != ELM_GETTING_MSG)
            {
                myELM327.printError();
                obd_state = TORQUE;
            }
            break;
        }

        case TORQUE:
        {
            float torque_r = myELM327.torque();
            if (myELM327.nb_rx_state == ELM_SUCCESS)
            {
                torque = torque_r;
                obd_state = BATTERY_VOLTAGE;
            }
            else if (myELM327.nb_rx_state != ELM_GETTING_MSG)
            {
                myELM327.printError();
                obd_state = BATTERY_VOLTAGE;
            }
            break;
        }

        case BATTERY_VOLTAGE:
        {
            float battery_voltage_r = myELM327.batteryVoltage();
            if (myELM327.nb_rx_state == ELM_SUCCESS)
            {
                battery_voltage = battery_voltage_r;
                obd_state = OIL_TEMP;
            }
            else if (myELM327.nb_rx_state != ELM_GETTING_MSG)
            {
                myELM327.printError();
                obd_state = OIL_TEMP;
            }
            break;
        }

        case OIL_TEMP:
        {
            float oil_temp_r = myELM327.oilTemp();
            if (myELM327.nb_rx_state == ELM_SUCCESS)
            {
                oil_temp = oil_temp_r;
                obd_state = FUEL_LEVEL;
            }
            else if (myELM327.nb_rx_state != ELM_GETTING_MSG)
            {
                myELM327.printError();
                obd_state = FUEL_LEVEL;
            }
            break;
        }

        case FUEL_LEVEL:
        {
            float fuel_level_r = myELM327.fuelLevel();
            if (myELM327.nb_rx_state == ELM_SUCCESS)
            {   
                fuel_level = fuel_level_r;
                obd_state = ENG_RPM;  // Riparti dal primo stato
            }
            else if (myELM327.nb_rx_state != ELM_GETTING_MSG)
            {
                myELM327.printError();
                obd_state = ENG_RPM;
            }
            break;
        }
    }
} 

// LOGGING DATI CENTRALINA TASK
void loggingCallback() {
  Serial.print("Rpm (giri/min): ");
  Serial.print(rpm);
  Serial.print(" | ");
  Serial.print("Kph (km/h): ");
  Serial.print(kph);
  Serial.print(" | ");
  Serial.print("Throttle position (%): ");
  Serial.print(throttle);
  Serial.print(" | ");
  Serial.print("Engine load (%): ");
  Serial.print(load);
  Serial.print(" | ");
  Serial.print("Coolant temp (°C): ");
  Serial.print(coolant_temp);
  Serial.print(" | ");
  Serial.print("Torque (Nm): ");
  Serial.print(torque);
  Serial.print(" | ");
  Serial.print("Battery voltage (V): ");
  Serial.print(battery_voltage, 2);
  Serial.print(" | ");
  Serial.print("Oil temp (°C): ");
  Serial.print(oil_temp);
  Serial.print(" | ");
  Serial.print("Fuel level (%): ");
  Serial.println(fuel_level);
}
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

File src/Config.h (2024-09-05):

#ifndef CONFIG_H
#define CONFIG_H

#define DEBUG

#define FORMAT_LITTLEFS_IF_FAILED true

#define NTP_SERVER1 "pool.ntp.org"
#define NTP_SERVER2 "time.nist.gov"
#define GMT_OFFSET 3600
#define DAYLIGHT_OFFSET 3600

#define FILE_SYSTEM "/littlefs"
#define PATH_STORAGE_DATA_DB "/littlefs/dati.db"
#define DB_FILE "/dati.db"

#define MAX_READINGS_ACCELEROMETRIA 0
#define MAX_READINGS_ALCOOL 10
#define MAX_READINGS_AIRQUALITY 10
#define MAX_READINGS_GPS 0
#define MAX_READINGS_LIQ_RAFFR 10
#define MAX_READINGS_OIL 10
#define MAX_READINGS_TORQUE 0 
#define MAX_READINGS_BATTERIA_V 0
#define MAX_READINGS_CARBURANTE_LEVEL 0
#define MAX_READINGS_ENGINE_LOAD 0
#define MAX_READINGS_RPM 0
#define MAX_READINGS_KPH 0
#define MAX_READINGS_THROTTLE 0

#define DEBUG_OBD true

#define ACCELEROMETRIA_READ_INTERVAL 15 * TASK_SECOND //15
#define AIR_READ_INTERVAL 20 * TASK_SECOND
#define GPS_READ_INTERVAL 30 * TASK_SECOND
#define CAR_OBD_STORAGE_INTERVAL 45 * TASK_SECOND //45
#define OBD_READ_INTERVAL 0.1 * TASK_SECOND
#define RESPONSE_TIME 5000
#define CENTRALINA_LOG 10 * TASK_SECOND
#define PROFILAZIONE_INTERVAL 10 * TASK_SECOND
#define ALLARMI_INTERVAL 6 * TASK_SECOND
#define WEEK (7 * 86400) * TASK_SECOND
#define SYNCHRONIZATION_DATA 2 * 60 * TASK_SECOND  // adesso sincronizzo ogni 60 sec, nella versione ufficiale la sincronizzazione avverrà in presenza di connessione e con un tempo maggiore di 24h dall'ultima sincronizzazione
#define CLEANING_ROUTINE 120 * TASK_SECOND     // adesso sono 120 secondi, nella versione ufficiale saranno 6h
#define CLEANING_MEMORY_FULL 300 * TASK_SECOND

#define GPS_TRACKING_SECURITY 120 * TASK_SECOND // ogni 2 min mando via GSM la posizione del veicolo
#define ACCIDENT_AND_ASSISTANCE 2 * TASK_SECOND // Rilevo frequentemente la forga G esercitata sul veicolo + la pressione del bottone

#define GPSBAUD 38400

#define LED_ROSSO 13
#define LED_GIALLO 14
#define LED_VERDE 27

#define BUTTON_PIN 4
#define ALCOOL_PIN 33
#define AIR_QUALITY_PIN 32

#define BUFFER_SIZE 1000

#define SYNCHRONIZED 1
#define NO_SYNCHRONIZED 0

#define DATE_TIME_FORMAT "%Y-%m-%d %H:%M:%S"
#define DATE_TIME_LEN 20

#define MAX_CAMPIONAMENTI_PROFILAZIONE 6 //3
#define MAX_CAMPIONAMENTI_ALLARMI_ROSSI 6
#define MAX_CAMPIONAMENTI_ALLARMI_GIALLI 6

#define FORZA_G 9.81
#define TOLLERANZA_OFF_ROAD 4
#define LAT_MIN 36.624
#define LAT_MAX 47.092
#define LON_MIN 6.626
#define LON_MAX 18.480
#define ACCEL_THRESHOLD 0.5
#define RPM_THRESHOLD 3000 // Giri al minuto considerato alto per il traino
#define SPEED_THRESHOLD 50 // Km/h considerato basso per il traino a RPM alti
#define LOAD_THRESHOLD 75 // Percentuale di carico del motore considerato alto
#define TORQUE_THRESHOLD 200 // Nm di coppia considerato alto
#define THROTTLE_THRESHOLD 60 // Percentuale di apertura della valvola a farfalla considerato alto

#define SOGLIA_ALCOOL 500 // Soglia reale: 2000 dato che in assenza di alcool ci si aggira interno ai 1600/1700
#define SOGLIA_QUAL_ARIA 700 // Soglia reale: 700 dato che in assenza di gas nocivi ci si aggira intorno ai 450/500
#define MAX_COOLANT_TEMP 120
#define MAX_OIL_TEMP 230
#define MIN_TORQUE_THRESHOLD 100
#define MAX_TORQUE_THRESHOLD 250

#define N_CLASSIFICATORI 5
#define ACCELERAZIONE_BRUSCA 0.5
#define DECELERAZIONE_BRUSCA -0.5
#define STERZATA_DX_BRUSCA 0.5
#define STERZATA_SX_BRUSCA -0.5
#define MAX_SPEED_CAR 220
#define MAX_RPM_CAR 6000
#define RANGE_INF 0.9
#define RANGE_SUP 1.3
#define LOAD_MIN 20
#define LOAD_MAX 50
#define CLEAN_PROFILAZIONE_DAY 30

#define SOGLIA_RILEVAMENTO_INCIDENTE 4
#define LEN_BUTTON_ARRAY 6

#define REGULAR_DISPLAY_FIRST_LINE "Nessun problema"
#define REGULAR_DISPLAY_SECOND_LINE "rilevato"
#define SOGLIA_ALLARMI_ROSSI 0.5
#define SOGLIA_ALLARMI_GIALLI 0.5

#endif

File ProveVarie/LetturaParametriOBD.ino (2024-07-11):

#include "BluetoothSerial.h"
#include "ELMduino.h"

BluetoothSerial SerialBT;
#define ELM_PORT SerialBT
#define DEBUG_PORT Serial

ELM327 myELM327;

uint8_t remoteAddres[] = { 0x10, 0x21, 0x3E, 0x4C, 0x6F, 0x3A };

typedef enum { ENG_RPM,
               SPEED,
               THROTTLE,
               LOAD,
               COOLANT_TEMP,
               TORQUE,
               BATTERY_VOLTAGE,
               OIL_TEMP,
               FUEL_LEVEL } obd_pid_states;
obd_pid_states obd_state = ENG_RPM;

float rpm = 0;
float mph = 0;
float throttle = 0;
float load = 0;
float coolant_temp = 0;
float torque = 0;
float battery_voltage = 0;
float oil_temp = 0;
float fuel_level = 0;

void setup() {
  DEBUG_PORT.begin(115200);
  ELM_PORT.begin("ArduHUD", true);
  SerialBT.setPin("1234");

  if (!ELM_PORT.connect(remoteAddres)) {
    DEBUG_PORT.println("Couldn't connect to OBD scanner - Phase 1");
    while (1)
      ;
  }

  if (!myELM327.begin(ELM_PORT, true, 2000)) {
    DEBUG_PORT.println("Couldn't connect to OBD scanner - Phase 2");
    while (1)
      ;
  }

  DEBUG_PORT.println("Connected to ELM327");
}

void loop() {
  switch (obd_state) {
    case ENG_RPM:
      {
        rpm = myELM327.rpm();
        if (myELM327.nb_rx_state == ELM_SUCCESS) {
          DEBUG_PORT.print("RPM: ");
          DEBUG_PORT.println(rpm);
          obd_state = SPEED;
        } else if (myELM327.nb_rx_state != ELM_GETTING_MSG) {
          myELM327.printError();
          obd_state = SPEED;
        }
        break;
      }

    case SPEED:
      {
        mph = myELM327.mph();
        if (myELM327.nb_rx_state == ELM_SUCCESS) {
          DEBUG_PORT.print("Speed (mph): ");
          DEBUG_PORT.println(mph);
          obd_state = THROTTLE;
        } else if (myELM327.nb_rx_state != ELM_GETTING_MSG) {
          myELM327.printError();
          obd_state = THROTTLE;
        }
        break;
      }

    case THROTTLE:
      {
        throttle = myELM327.throttle();
        if (myELM327.nb_rx_state == ELM_SUCCESS) {
          DEBUG_PORT.print("Throttle (%): ");
          DEBUG_PORT.println(throttle);
          obd_state = LOAD;
        } else if (myELM327.nb_rx_state != ELM_GETTING_MSG) {
          myELM327.printError();
          obd_state = LOAD;
        }
        break;
      }

    case LOAD:
      {
        load = myELM327.engineLoad();
        if (myELM327.nb_rx_state == ELM_SUCCESS) {
          DEBUG_PORT.print("Engine Load (%): ");
          DEBUG_PORT.println(load);
          obd_state = COOLANT_TEMP;
        } else if (myELM327.nb_rx_state != ELM_GETTING_MSG) {
          myELM327.printError();
          obd_state = COOLANT_TEMP;
        }
        break;
      }

    case COOLANT_TEMP:
      {
        coolant_temp = myELM327.engineCoolantTemp();
        if (myELM327.nb_rx_state == ELM_SUCCESS) {
          DEBUG_PORT.print("Coolant Temp (C): ");
          DEBUG_PORT.println(coolant_temp);
          obd_state = TORQUE;
        } else if (myELM327.nb_rx_state != ELM_GETTING_MSG) {
          myELM327.printError();
          obd_state = TORQUE;
        }
        break;
      }

    case TORQUE:
      {
        torque = myELM327.torque();
        if (myELM327.nb_rx_state == ELM_SUCCESS) {
          DEBUG_PORT.print("Torque (Nm): ");
          DEBUG_PORT.println(torque);
          obd_state = BATTERY_VOLTAGE;
        } else if (myELM327.nb_rx_state != ELM_GETTING_MSG) {
          myELM327.printError();
          obd_state = BATTERY_VOLTAGE;
        }
        break;
      }

    case BATTERY_VOLTAGE:
      {
        battery_voltage = myELM327.batteryVoltage();
        if (myELM327.nb_rx_state == ELM_SUCCESS) {
          DEBUG_PORT.print("Battery Voltage (V): ");
          DEBUG_PORT.println(battery_voltage);
          obd_state = OIL_TEMP;
        } else if (myELM327.nb_rx_state != ELM_GETTING_MSG) {
          myELM327.printError();
          obd_state = OIL_TEMP;
        }
        break;
      }

    case OIL_TEMP:
      {
        oil_temp = myELM327.oilTemp();
        if (myELM327.nb_rx_state == ELM_SUCCESS) {
          DEBUG_PORT.print("Oil Temp (C): ");
          DEBUG_PORT.println(oil_temp);
          obd_state = FUEL_LEVEL;
        } else if (myELM327.nb_rx_state != ELM_GETTING_MSG) {
          myELM327.printError();
          obd_state = FUEL_LEVEL;
        }
        break;
      }

    case FUEL_LEVEL:
      {
        fuel_level = myELM327.fuelLevel();
        if (myELM327.nb_rx_state == ELM_SUCCESS) {
          DEBUG_PORT.print("Fuel Level (%): ");
          DEBUG_PORT.println(fuel_level);
          obd_state = ENG_RPM;  // Riparti dal primo stato
        } else if (myELM327.nb_rx_state != ELM_GETTING_MSG) {
          myELM327.printError();
          obd_state = ENG_RPM;  // Riparti dal primo stato
        }
        break;
      }

    default:
      DEBUG_PORT.println("Unknown state.");
      obd_state = ENG_RPM;
      break;
  }
}

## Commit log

2024-04-02 Introdotti i dati relativi al primo tragitto
    [datiTragitto.csv]
2024-04-03 Aggiunto file sulla funzionalità di tracking
2024-04-03 Riorganizzati alcuni file
    [datiTragitto.csv]
2024-04-03 Aggiunta di alcune cartelle
    [datiTragitto.csv]
2024-04-04 Lettura inerente alla segnalazione di allarmi
2024-04-05 Corretto file sulla segnalazione allarmi
    [datiTragitto.csv]
2024-04-11 Sistemazione generale di alcuni file
2024-05-12 Aggiunta politica di storage molto molto basic
2024-05-13 Introdotta frequenza di campionamento (basic)
2024-05-13 Modificate le freq di campionamento da milliSec a Sec
2024-05-14 Ridefiniti i nomi dei prototipi di funzione
2024-05-14 Rese alcune funzioni private a livello di classe
2024-05-14 Refactoring: migliorata la leggibilità del flusso di set up
2024-05-15 Aggiunta struttura generale di memorizzazione dati
2024-05-17 Corretta le due tabelle relative ai tempi di campionamento e ai dati statistici
2024-05-20 Gestione pulizia record in caso di riempimento memoria
2024-05-20 Aggiunto feature relativa all'intervento di garbage collector in caso di memoria piena
2024-05-21 Aggiunto meccanismo di sincronizzazione
2024-05-22 Aggiunta e rimozione di alcuni sensori
2024-05-23 Aggiunto supporto per device I2C
2024-05-23 Definizione politica di pulizia dati (GB)
2024-05-24 Integrato il meccanismo di sincronizzazione
2024-05-25 Aggiunto task per la sincronizzazione dei dati
2024-05-28 Introdotte funzionalità di sincronizzazione e pulizia dati
2024-05-30 Esempio di ricezione dati lato server
2024-05-31 Aggiunti dati ricevuti dal server con policy intelligente di storage
2024-05-31 Introdotta politica di ottimizzazione del tempo di storage dei dati
2024-05-31 Aggiunta la possibilità di reperire il tempo di storage dal db
2024-05-31 Introdotto prototipo funzione sul tempo di storage
2024-06-01 Aggiunta accelerometria
2024-06-01 Aggiunti i tempi di campionamento per l'accelerometria
2024-06-01 Aggiornati i dataWithPolicy.txt con accelerometria
2024-06-03 Introdotti Alcool e Air quality per la politica di storage
2024-06-03 Introdotta politica di storage
2024-06-21 Aggiunta la lettura da OBDII
2024-06-21 Introdotti rpm e temperatura liquido di raffreddamento per la politica di storage
2024-06-25 Trattata la logica per la segnalazione di allarmi
2024-06-26 Ultimata la logica per la segnalazione allarmi
2024-07-07 Sistemato diagramma di flusso
2024-07-07 Reso visibile diagramma di flusso
2024-07-08 Aggiornate le tabelle di storage
2024-07-08 Corretto errore di battitura
2024-07-08 Introdotta coppia motore "torque"
2024-07-09 Rimosso sensore "bussola"
2024-07-09 Introdotta la coppia motore "torque"
2024-07-09 Definito il comportamento gps-incidente-assistenza
2024-07-16 Corretto titolo di alcuni paragrafi e sottoparagrafi
2024-07-24 Aggiunto circuito black box
    [circuito.fzz]
2024-08-18 Aggiunta di immagini sulla segnalazione di allarmi
2024-08-19 Guida spericolata con tempi di campionamento ristretti
2024-08-22 Aggiornati i valori di soglia per la tabella t2
2024-09-05 Eliminato Elaborato directory
    [circuito.fzz]
